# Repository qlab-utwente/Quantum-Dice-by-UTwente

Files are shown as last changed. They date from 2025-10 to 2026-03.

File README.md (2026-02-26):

# QuantumDice by UTwente

> NEW RELEASE 📢: Quantum Dice V2.0.1
[see](https://github.com/qlab-utwente/Quantum-Dice-by-UTwente/releases)

- Every Quantum Die can entangle with another. No need to use pairs of QD's
- Implementation of Teleportation protocol with 3 or more Quantum Die [See User Guide](USER_GUIDE.md)
- Simplified configuration file
- If you are on version V1.x.x.x  [use this guide](MIGRATION_GUIDE_V1.1.X_TO_V2.0.0.md) to migrate to V2.0.x
- Lots software changes to create a more robust, better maintainable software framework.

Quantum Dice trailer (https://www.youtube.com/watch?v=Ihkr6yNOIKE)

flyer

In this repo you can find all relevant files, including assembly instructions, 3D printing files, and the parts list. Based on this information, you can build the Quantum Dice yourself.

For further information see [Quantum Dice by University of Twente](https://www.utwente.nl/en/mesaplus/education/quantum-dice/)

You can find more information about the dice in our article, including didactical approaches, for which a preprint is available on [*arXiv*](https://arxiv.org/abs/2510.04931)

Content of this repo:

- [Arduino Code](/QuantumDice/)
- [Firmware upload procedure](/SETUP.md)
- [3D printfiles](/3D%20print%20files/)
- [Construction manual](/3D%20print%20files/ConstructionManual.md)
- [Bill of Material and parts sourcing calculator](/3D%20print%20files/Bill%20of%20Material%20quantum%20dice.xlsx)
- [Arduino Technical documentation](/QuantumDice/technical%20documentation.md) and [Installation and configuration Arduino IDE](Arduino/QuantumDice/README.md)

## Contribution

Your contribution is welcome and appreciated to improve the quality and functionality of the Quantum Dice.

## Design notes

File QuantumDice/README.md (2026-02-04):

# Programming the QuantumDice by UTwente

---

## Table of Contents

1. [Introduction](#1-introduction)
2. [Technical Overview](#2-technical-overview)
3. [Arduino IDE Setup](#3-arduino-ide-setup)
   - 3.1 [Install Arduino IDE](#31-install-arduino-ide)
   - 3.2 [Install ESP32 Board Support](#32-install-esp32-board-support)
   - 3.3 [Configure Board Settings](#33-configure-board-settings)
   - 3.4 [Install Required Libraries](#34-install-required-libraries)
4. [First Time Setup](#4-first-time-setup)
   - 4.1 [Initial Upload - Blink Test](#41-initial-upload---blink-test)
   - 4.2 [Board Configuration](#42-board-configuration)
5. [Programming the QuantumDice](#5-programming-the-quantumdice)
   - 5.1 [Prepare for Upload](#51-prepare-for-upload)
   - 5.2 [Upload the Sketch](#52-upload-the-sketch)
   - 5.3 [Verify Operation](#53-verify-operation)

---

## 1. Introduction

This guide provides step-by-step instructions for programming and configuring the QuantumDice hardware. Before beginning, ensure you have a USB-C cable and have installed the Arduino IDE on your computer.

> **⚠️ CRITICAL SAFETY WARNING:** Always disconnect the 4-wire power cable before connecting the USB cable to prevent permanent damage to the board! For easier access to the boot and reset buttons and to avoid stress on the display cables, disconnect both the upper and lower screens from the ProcessorBoard during programming.

---

## 2. Technical Overview

The QuantumDice is built on an **ESP32-S3 N16R8 module** and includes several key components:

**Partitions:**
A custom partition setting is used to include a **littlFS** partition. Therefor the file `partitions.csv` must be added to the sketch folder. See [partitions.csv](partitions.csv)

**Display System:**

- Six round TFT displays with SPI interface
- Each display controlled via individual CS-pin connected to a digital port

**Sensors and Components:**

- **BNO055 IMU sensor**: Measures rotation and position of the dice. I2C protocol.
- ESP32 random generator
- Push button for user input
- Battery voltage monitoring system

**Communication:**

- ESP-NOW protocol enables peer-to-peer communication between paired dice
- Automatic neighbor discovery via mesh networking

**Data Storage:**

- Configuration data stored in LittleFS
- Configuration file (called XXXXX_config.txt where XXXXX is the Set Name of the dice)
- The system automatically detects and loads the config file on boot
- [See example configs](/example_configs/)

**Reference Documentation:**

- [ESP32-S3 N16R8 Datasheet](https://www.espressif.com/sites/default/files/documentation/esp32-s3-wroom-1_wroom-1u_datasheet_en.pdf)
- [BNO055 IMU Datasheet](https://nl.mouser.com/datasheet/3/1046/1/bst-bno055-ds000.pdf)

---

## 3. Arduino IDE Setup

### 3.1 Install Arduino IDE

Download and install the latest version of [Arduino IDE 2.x](https://docs.arduino.cc/software/ide/#ide-v2) for your operating system.

### 3.2 Install ESP32 Board Support

1. Open Arduino IDE
2. Navigate to **File > Preferences**
3. In the "Additional Boards Manager URLs" field, add:

   ```
   https://raw.githubusercontent.com/espressif/arduino-esp32/gh-pages/package_esp32_index.json
   ```

4. Click **OK** to save
5. Go to **Tools > Board > Boards Manager**
6. Search for "ESP32"
7. Install **"esp32 by Espressif Systems"**
8. Wait for installation to complete

> **⚠️ IMPORTANT:** Use ESP32 version 3.3.2 from the Board Manager for compatibility.

### 3.3 Configure Board Settings

Select the following settings from the **Tools** menu:

| Setting | Value |
|---|---|
| **Board** | ESP32S3 Dev Module |
| **USB CDC On Boot** | Enabled *(critical for native USB)* |
| **USB Mode** | USB-OTG (TinyUSB) or Hardware CDC and JTAG |
| **Flash Size** | 16MB (128Mb) |
| **PSRAM** | OPI PSRAM |
| **Partition Scheme** | custom |

### 3.4 Install Required Libraries

Install the following libraries via **Tools > Manage Libraries**:

- BNO055 by Adafruit
- Adafruit Unified Sensor
- Adafruit GFX
- Adafruit GC9A01A
- Button2

Your Arduino IDE is now ready for QuantumDice development.

---

## 4. First Time Setup

When connecting a fresh ESP32-S3 module (ESP32-S3N16R8) to Arduino IDE for the first time, you may see continuous reboot messages in the Serial monitor:

```
invalid header: 0xffffffff
invalid header: 0xffffffff
ESP-ROM:esp32s3-20210327
Build:Mar 27 2021
rst:0x7 (TG0WDT_SYS_RST),boot:0x2b (SPI_FAST_FLASH_BOOT)
Saved PC:0x40048839
invalid header: 0xffffffff
...
```

This is **completely normal** for a fresh module from the supplier. Here's what's happening:

- **`invalid header: 0xffffffff`** - The bootloader is searching for valid firmware in flash memory but finding only erased flash (0xFFFFFFFF = all bits set high = empty state)
- **`rst:0x7 (TG0WDT_SYS_RST)`** - Watchdog timer reset triggered because no valid firmware was found to execute
- **Bootloop** - The module continuously resets because there's no program to run

The ESP32-S3 module has never been programmed and needs its first firmware upload.

### 4.1 Initial Upload

When programming an ESP32-S3 for the first time, a specific initialization procedure is required.

> **⚠️ REMINDER:** Disconnect the 4-wire power cable before connecting USB!

#### Step 1: Load the QuantumDice sketch

1. Go to **File > Open** and select the QuantumDice.ino file

#### Step 2: Enter Download Mode

For the first upload, manually put the ESP32-S3 into download mode. See attached image for the locations of the **BOOT** and **RESET** button.


1. **Hold down** the **BOOT** button
2. While holding BOOT, **press and release** the **RESET** button
3. **Release** the **BOOT** button

Your board is now in download mode and ready to receive code.

*Alternative method:* Hold the BOOT button while plugging in the USB cable.

#### Step 3: Select COM Port

1. Go to **Tools > Port**
2. Select the COM port for your ESP32-S3:
   - **Windows:** COM# (e.g., COM3)
   - **Mac:** /dev/cu.usbmodem# or /dev/tty.usbmodem#
   - **Linux:** /dev/ttyACM# or /dev/ttyUSB#

#### Step 4: Upload the Sketch

1. Click the **Upload** button (right arrow icon)
2. Wait for compilation and upload to complete
3. You should see "Connecting..." followed by upload progress
4. Once complete, **press the RESET button** on your board

The QuantumDice should now be running.

**After this initial upload, future uploads will not require the BOOT button procedure.**

### 4.2 Board Configuration

The board configuration is performed with a XXXXX_config.txt file. You can use the  enclosed [TEST1_config.txt](/example_configs/TEST1_config.txt) as a starter.

Uploading the config file with
[ESPConnect](https://thelastoutpostworkshop.github.io/ESPConnect/) tool (need Google Chrome to run). For complete instructions, see the [Setup Guide](../README.md).

---

## 5. Programming the QuantumDice

### 5.1 Prepare for Upload

> **⚠️ REMINDER:** Always disconnect the 4-wire power cable before connecting USB!

**Before programming:**

1. Remove the top and bottom (blue) cups from the dice
2. Disconnect the 4-wire power cable
3. Optionally disconnect the display FPC cables for easier access to buttons
4. Connect a USB-C cable to the underside of the ProcessorPCB

### 5.2 Upload the Sketch

1. Open the sketch in Arduino IDE
2. Connect the ProcessorPCB via USB-C cable
3. Select the correct communication port from **Tools > Port**
4. Click **Upload** to compile and upload the sketch
5. Wait for the upload to complete

### 5.3 Verify Operation

After uploading, open the **Serial Monitor** (baud rate: **115200**) to view debugging information.

**Expected Startup Sequence:**

The Serial Monitor will display:

- Loaded configuration (Dice ID, colors, timing constants)
- Hardware pin configuration
- Display initialization
- BNO055 sensor detection and calibration status
- ESP-NOW initialization with MAC address
- State machine initialization
- Welcome sequence with logo displays

**Example Output:**

```text
[LOG]	
[LOG]	╔════════════════════════════════════════╗
[LOG]	║      QUANTUM DICE INITIALIZATION       ║
[LOG]	╚════════════════════════════════════════╝

[LOG]	/home/twan/Development/Quantum-Dice-by-UTwente/QuantumDice/QuantumDice.ino Jan 26 2026 21:09:54
[L] FW: 2.0.0
[LOG]	Step 1: Initializing filesystem and configuration...
[LOG]	
[DEBUG]	Mounting LittleFS...
[DEBUG]	LittleFS mounted successfully
[D] Total: 4194304 bytes, Used: 8192 bytes
[D] Found config file: DEFAULT_config.txt
[D] Loading global config from /DEFAULT_config.txt...
[DEBUG]	LittleFS mounted successfully
[DEBUG]	Loading config from /DEFAULT_config.txt
[D] Loaded 4 entanglement colors
[DEBUG]	Config loaded successfully
[D] Loaded global config from: /DEFAULT_config.txt
[LOG]	✓ Filesystem and configuration ready!

[LOG]	=== Global Configuration ===
[L] Dice ID: DEFAULT
[L] X Background: 0x0000 (0)
[L] Y Background: 0x0000 (0)
[L] Z Background: 0x0000 (0)
[L] Entangle Colors (4): ffe0, 7e0, 7ff, f81f
[LOG]	
[L] Color Flash Timeout: 250 ms
[L] RSSI Limit: -35 dBm
[L] Is SMD: true
[L] Is Nano: false
[L] Deep Sleep Timeout: 300000 ms
[L] Checksum: 0x00
[LOG]	============================
[LOG]	
Step 2: Initializing hardware...
[LOG]	
Initializing hardware pins...
Hardware pins initialized successfully!
[LOG]	
=== Hardware Pin Configuration ===
[L] Board Type: DEVKIT
[L] Screen Type: SMD
[LOG]	
TFT Display Pins:
[L]   CS:  GPIO10
[L]   RST: GPIO48
[L]   DC:  GPIO47
[LOG]	
Screen CS Pins:
[L]   Screen 0: GPIO4
[L]   Screen 1: GPIO5
[L]   Screen 2: GPIO6
[L]   Screen 3: GPIO7
[L]   Screen 4: GPIO15
[L]   Screen 5: GPIO16
[L] 
ADC Pin: GPIO2
[LOG]	==================================

[L]  - Dice ID: [LOG]	DEFAULT
[L] Board type: [LOG]	DEVKIT
[L] Connectie type isSMD: [LOG]	SMD
Initializing displays...
Displays initialized successfully!
[D] Qlab logo on screen: [DEBUG]	14
[LOG]	
Step 3: Initializing IMU sensor...
[LOG]	
[L] Initializing BNO055... E (3501) i2c.master: I2C transaction unexpected nack detected
E (3502) i2c.master: s_i2c_synchronous_transaction(945): I2C transaction failed
E (3503) i2c.master: i2c_master_transmit_receive(1248): I2C transaction failed
E (3520) i2c.master: I2C transaction unexpected nack detected
...
E (3773) i2c.master: s_i2c_synchronous_transaction(945): I2C transaction failed
E (3775) i2c.master: i2c_master_transmit_receive(1248): I2C transaction failed
[LOG]	detected.
[L] Applying axis remapping... [LOG]	done.
[L] Waiting for stable readings... [L] OK ([L] 9.46[L]  m/s² after [L] 1[LOG]	 attempts)
[L] Stabilizing baseline... [LOG]	done.
[LOG]	✓ BNO055 initialization complete!
[D] QR code on screen: [DEBUG]	1
[D] Einstein on screen: [DEBUG]	8
[D] UTwente logo on screen: [DEBUG]	7
[LOG]	
Step 4: Completing initialization...
[LOG]	
ESP-NOW initialized successfully!
[D] MAC Address is : D0[D] :CF[D] :13[D] :36[D] :15[D] :90[D] 
[LOG]	ESP-NOW initialized successfully!
[D] MAC Address is : D0[D] :CF[D] :13[D] :36[D] :15[D] :90[D] 
[LOG]	StateMachine Begin: Calling onEntry for initial state
[D] StateMachine: CLASSIC | IDLE | PURE
[DEBUG]	=== Entering CLASSIC MODE ===
[DEBUG]	Entering N2 case
[DEBUG]	Entering N3 case
[DEBUG]	Entering N6 case
[DEBUG]	Entering N5 case
[DEBUG]	Entering N4 case
[DEBUG]	Entering N1 case
[LOG]	
[LOG]	╔════════════════════════════════════════╗
[LOG]	║       SETUP COMPLETE - READY!          ║
[LOG]	╚════════════════════════════════════════╝
```

> **Note:** You may see some I2C error messages during initialization. These are typically harmless if the sensors are detected successfully afterward.

**Your QuantumDice is now programmed and ready to use!**

---

## Troubleshooting

**Upload fails:**

- Ensure BOOT button procedure was followed for first-time uploads
- Check USB cable connection and try a different cable
- Verify correct COM port is selected
- Confirm 4-wire power cable is disconnected

**Sensor errors:**

- Check I2C connections
- Verify sensors are properly seated

**Display issues:**

- Ensure FPC cables are properly connected
- Check CS pin assignments in code match your hardware version

---

*For additional support, refer to the QuantumDice GitHub repository or contact the UTwente development team.*

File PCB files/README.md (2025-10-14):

# Power Board and Processor Board Information

In this directory you find the files needed to order your Printed Circuit Boards (PCB) for the ProcessorPCB (left) and the PowerPCB (right).

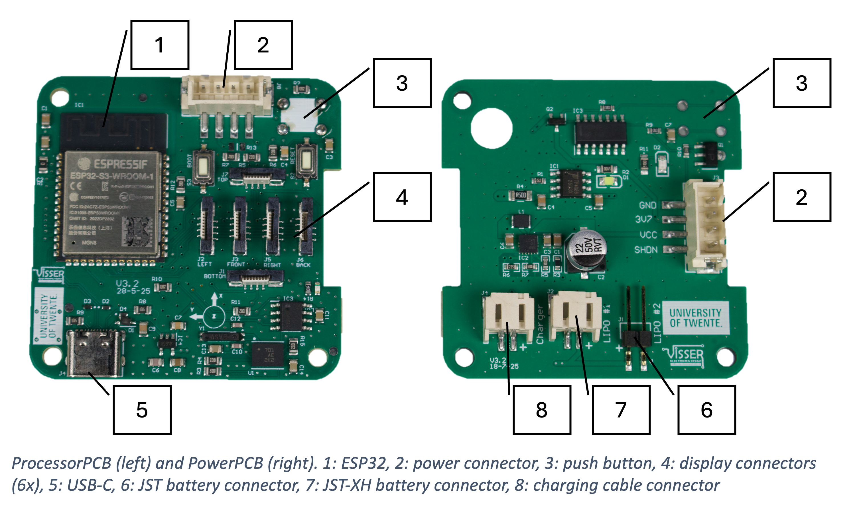
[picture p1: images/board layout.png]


Per board the following files are available:
- Gerber files in ZIP format
- Bill of Material (BOM) list
- Pick and place file

---

## PCB Fabrication

The Gerber files can be used to fabricate the PCBs. This can be done by [JLCPCB.com](https://www.jlcpcb.com) or [PCBway.com](https://www.pcbway.com) or equivalent.

Important to notice is that the ProcessorPCB is a 4-layer board and the PowerPCB is a 2-layer board.

---

## Assembly of Boards

In the BOM file the required components are listed. The numbers refer to JLCPCB Part Numbers. This number can be used to order parts from JLCPCB.

JLCPCB offers a service to assemble the PCB after PCB fabrication called **PCB Assembly**.

After uploading the Gerber files in JLCPCB (default settings are OK), select PCB Assembly.

### ProcessorPCB

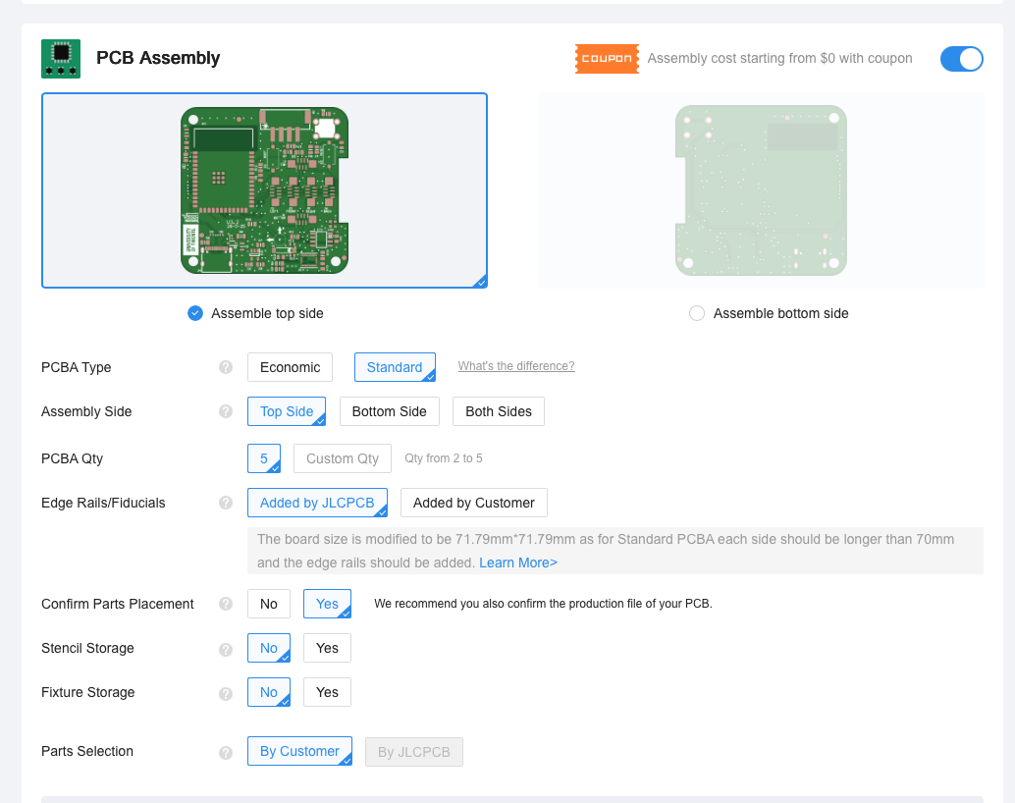
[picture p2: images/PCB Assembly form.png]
PCB Assembly Form


- Select *Assemble top side*
- Select *Standard*
- Select *Confirm Parts Placement* (From my own experience JLCPCB can make mistakes with the orientation of components. With this option you will be asked to verify component orientation)

Next upload BOM and Pick and Place file.

The orientation is indicated in Magenta (right PCB):

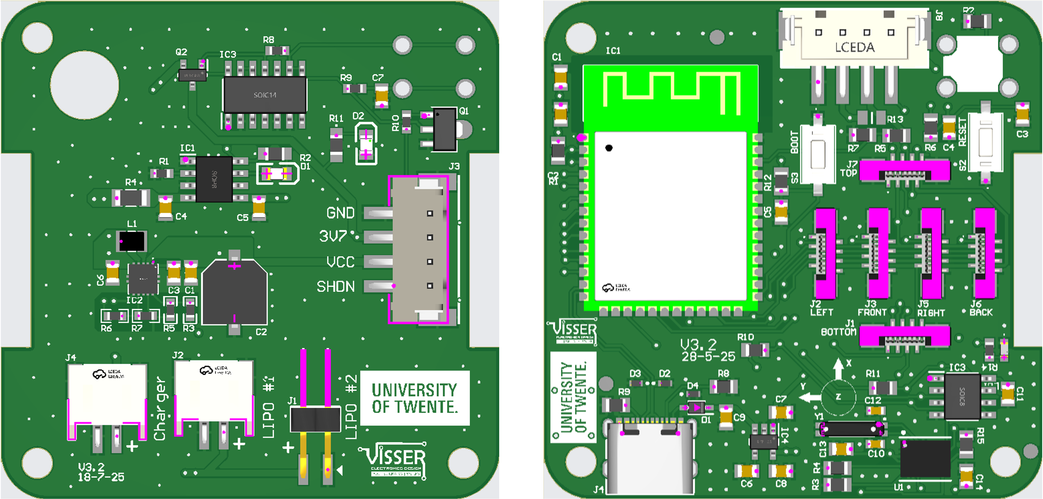
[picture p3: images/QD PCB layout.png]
QD PCB Layout


### PowerPCB

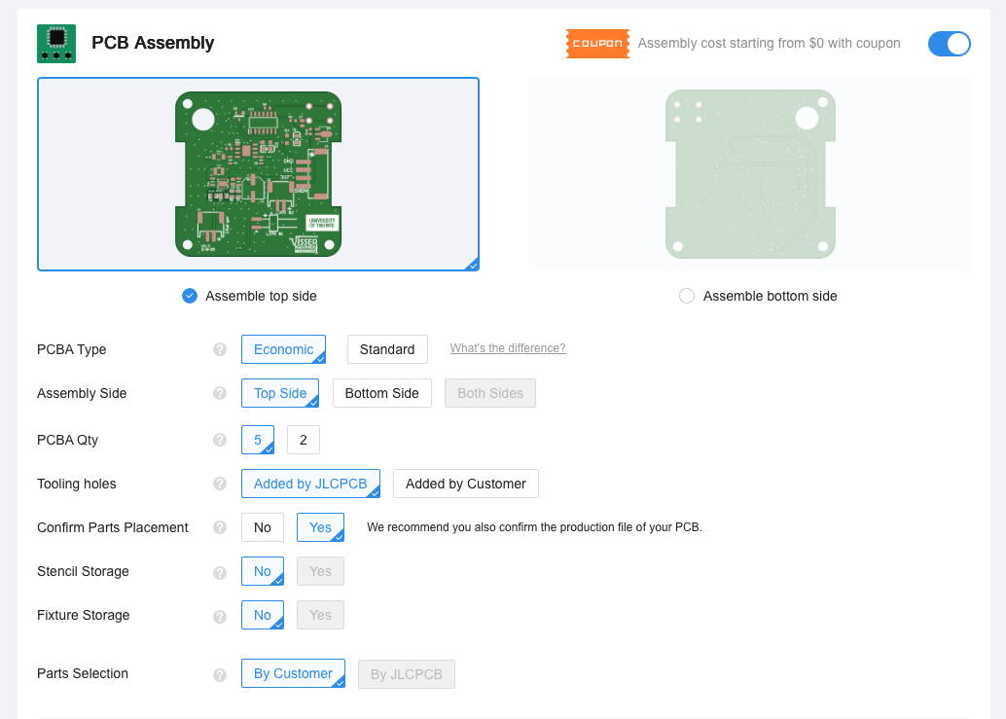
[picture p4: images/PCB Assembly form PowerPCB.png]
PCB Assembly Form PowerPCB


- Select *Assemble top side*
- Select *Economic*
- Select *Confirm Parts Placement* (From my own experience JLCPCB can make mistakes with the orientation of components. With this option you will be asked to verify component orientation)

Next upload BOM and Pick and Place file.

The orientation of D1 and D2 can go wrong (opposite mount). See detail:

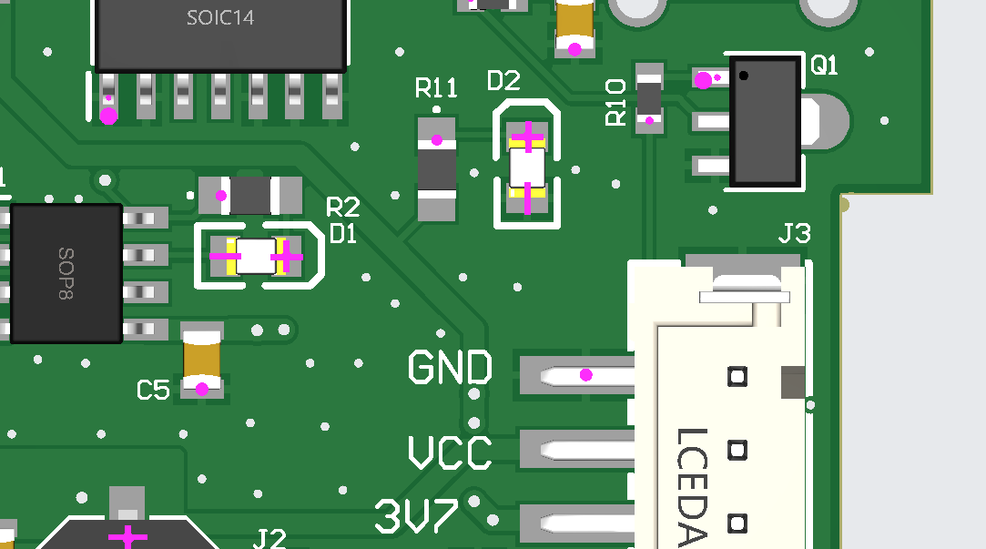
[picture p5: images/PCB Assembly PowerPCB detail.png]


### Soldering push button

On both PCB's a **Tactile Pushbutton 4pin 6*6*6 mm** (See BOM list) must be soldered on the *Bottom Side* of the PCB. The height of the button must be 6 mm!

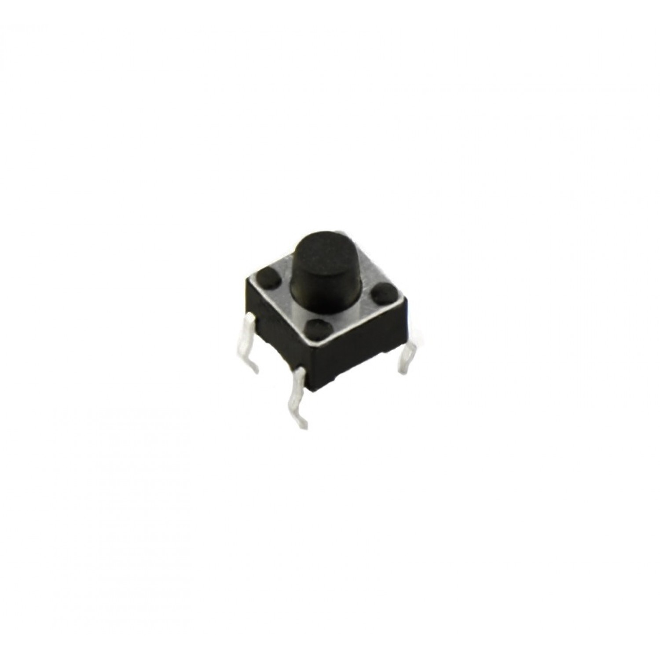
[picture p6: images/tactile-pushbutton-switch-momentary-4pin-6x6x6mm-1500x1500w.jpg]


## Final Notes

After assembly, carefully inspect both boards for:
- Correct component orientation
- Proper soldering quality
- No bridged connections

Once you receive your assembled PCBs, verify all components against the BOM before powering up the boards for the first time.

For questions or issues during the ordering process, refer to the manufacturer's documentation or contact their support team.

---

**Good luck with your PCB fabrication and assembly!**

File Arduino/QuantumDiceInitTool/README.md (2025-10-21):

# Quantum Dice Init Tool - User Manual

## Overview

This tool provides a comprehensive setup interface for initializing ESP32-S3 based Quantum Dice devices. It handles MAC address retrieval, cryptographic chip configuration, IMU sensor calibration, and device configuration storage.

Once uploaded open Serial monitor 

---

## Menu Items Reference

### Main Menu Options

| Option | Function | Purpose | Permanent? |
|---|---|---|---|
| **1** | Get MAC Address | Retrieves and formats the device's unique MAC address for configuration | No |
| **2** | Configure ATECC508a | Initializes and locks the cryptographic co-processor with SparkFun settings | **YES - PERMANENT** |
| **3** | Calibrate BNO055 Sensor | Performs IMU sensor calibration and stores offsets in EEPROM | No (can recalibrate) |
| **4** | Test BNO055 Sensor | Displays live sensor data to verify calibration quality | No |
| **5** | Clear EEPROM | Erases all EEPROM data (calibration + configuration) | No (requires confirmation) |
| **6** | Configure EEPROM Settings | Interactive device configuration setup and storage | No (can reconfigure) |
| **M** | Show Menu | Redisplays the main menu | No |

---

## First-Time Setup Workflow

Follow this step-by-step guide to initialize a new device from scratch (empty EEPROM).

---

### Step 1: Get MAC Address

**Purpose:** Retrieve the unique MAC address needed for device identification and configuration.

1. Press **`1`** in the main menu
2. Wait for WiFi initialization (1-2 seconds)
3. You'll see output similar to:
```
   --- Getting MAC Address ---
   Original MAC Address: D0:CF:13:36:40:88
```

4. **Copy** the formatted MAC address line
5. **Save it** for use in Step 4 (Configuration)
6. Press **`M`** to return to menu

**Notes:**
- Each device has a unique MAC address
- You'll need this for Device A, B1, and B2 configurations

---

### Step 2: Configure ATECC508a Cryptographic Chip

**⚠️ WARNING: THIS STEP IS PERMANENT AND CANNOT BE UNDONE!**

**Purpose:** Initialize the hardware security chip for cryptographic operations and secure key storage. This device must be locked first before it can be used.

1. Press **`2`** in the main menu
2. The tool will detect the ATECC508a and display:
```
   ✓ ATECC508a detected - I2C connection good
   Serial Number: 0123456789ABCDEF
   Config Zone: NOT Locked
   Data/OTP Zone: NOT Locked
   Data Slot 0: NOT Locked
```

3. Type **`Y`** to confirm (or any other key to cancel)
4. The configuration process will run:
```
   Write Config:   ✓ Success
   Lock Config:    ✓ Success
   Key Creation:   ✓ Success
   Lock Data-OTP:  ✓ Success
   Lock Slot 0:    ✓ Success
```

5. Verify all steps show **`✓ Success`**
6. Press **`M`** to return to menu

**Notes:**
- The public key will be generated and displayed after locking
- If already configured, the tool will inform you and skip this step

---

### Step 3: Calibrate BNO055 IMU Sensor

**Purpose:** Calibrate the 9-axis IMU sensor for accurate motion detection and orientation tracking.

1. Press **`3`** in the main menu
2. The tool will detect the BNO055 and display sensor details
3. For new devices, it will show:
```
   ⚠ No calibration data found in EEPROM
   Starting calibration process...
```

4. **Calibration Process:**

   See [Bosch calibration instruction on Youtube](https://www.youtube.com/watch?v=Bw0WuAyGsnY)
   and [Adafruit calibration article](https://learn.adafruit.com/adafruit-bno055-absolute-orientation-sensor/device-calibration)
   
   The tool will display real-time calibration status:
```
   Cal: Sys:0 G:0 A:0 M:0 | Linear: 0.450 m/s² [⚠⚠ HIGH OFFSET - Keep calibrating!]
```

   **Calibration values range from 0 (uncalibrated) to 3 (fully calibrated):**
   - **Sys** = System (overall status)
   - **G** = Gyroscope
   - **A** = Accelerometer  
   - **M** = Magnetometer

5. **Perform these movements until all values reach 3:**

   **For Magnetometer (M):**
   - Move the device in a **figure-8 pattern**
   - Cover all orientations in 3D space
   - Continue until M reaches 3

   **For Gyroscope (G):**
   - **Slowly rotate** the device around all three axes
   - X-axis: rotate left/right
   - Y-axis: rotate forward/backward
   - Z-axis: rotate clockwise/counterclockwise
   
   **For Accelerometer (A):**
   - Place device in **6 different orientations**:
     - Face up, face down
     - Left side, right side
     - Top edge, bottom edge
   - Hold each position for 2-3 seconds

6. **Monitor Linear Acceleration Offset:**
```
   Linear: 0.120 m/s² [✓✓ Excellent offset!]
```
   
   **Target: < 0.15 m/s²**
   - **< 0.15**: Excellent ✓✓
   - **0.15-0.30**: Good ✓
   - **0.30-0.50**: Moderate ⚠
   - **> 0.50**: High - keep calibrating ⚠⚠

7. When fully calibrated (Sys:3 G:3 A:3 M:3):
```
   ✓ Fully calibrated!
   Final linear acceleration offset: 0.0823 m/s² - Excellent! ✓✓
   
   Saving calibration to EEPROM...
   ✓ Calibration saved!
```

8. Press **`M`** to return to menu

**Notes:**
- Calibration typically takes 2-5 minutes
- Move **slowly and smoothly** for best results
- Press **`Q`** anytime to quit without saving
- For acceleration testing 
- You can recalibrate anytime from the menu
- Use Option 4 to test sensor accuracy after calibration

---

### Step 4: Configure Device Settings in EEPROM

**Purpose:** Set up device-specific parameters including MAC addresses, display colors, and operational settings.

1. Press **`6`** in the main menu
2. For empty EEPROM, you'll see:
```
   ⚠ No valid configuration found in EEPROM
   Let's configure your device!
   
   Creating new configuration...
```

3. **Interactive Field-by-Field Configuration:**

   The tool will prompt for each setting with a default value shown in brackets:
```
   ----------------------------------------
   Dice ID [TEST1]: 
```

   - maximum of 5 characters
   - **Press ENTER** to accept the default value
   - **Type a new value** and press ENTER to change it
   - Important fields: Dice ID, Device A MAC, Device B MAC. The remaining fields the defaults are ok
   - When using the Quantum Dice for **Teleportation** demonstration, the MAC Address of the 3rd dice is needed at Device B2 MAC. 

4. **Configuration Fields:**

   | Field | Description | Example | Notes |
   |-------|-------------|---------|-------|
   | **Dice ID** | Unique identifier (max 5 chars) | `DICE_A` | Alpha-numeric |
   | **Device A MAC** | Primary device MAC address | `D0:CF:13:36:40:88` | From Step 1 |
   | **Device B1 MAC** | Secondary device 1 MAC | `D0:CF:13:33:58:5C` | From Step 1 |
   | **Device B2 MAC** | Secondary device 2 MAC | `DC:DA:0C:21:02:44` | From Step 1 |
   | **X Background Color** | Display color (hex) | `0x0000` | 16-bit RGB565 |
   | **Y Background Color** | Display color (hex) | `0x0000` | 16-bit RGB565 |
   | **Z Background Color** | Display color (hex) | `0x0000` | 16-bit RGB565 |
   | **Entanglement AB1 Color** | Connection color (hex) | `0xFFE0` | Yellow |
   | **Entanglement AB2 Color** | Connection color (hex) | `0x07E0` | Green |
   | **RSSI Limit** | Signal strength threshold for entanglement (dBm) | `-35` | -100 to 0. |
   | **Is NANO board?** | Board type | `N` | Y=NANO, N=DEVKIT |
   | **Is SMD screen?** | Screen type | `Y` | Y=SMD, N=HDR |
   | **Always Seven mode?** | Debug mode | `N` | Y/N |
   | **Random Switch Point** | Randomness threshold (0-100) | `50` | 0-100 |
   | **Tumble Constant** | Minimum amount of rolling | `0.2` | 0.0-10.0 |
   | **Deep Sleep Timeout** | Auto-sleep time (seconds) | `300` | 10-3600 |

5. **MAC Address Entry:**
   
   Enter MAC addresses in the format: `AA:BB:CC:DD:EE:FF`
   
   Example:
```
   Device A MAC [D0:CF:13:36:40:88]
   Enter MAC (format: AA:BB:CC:DD:EE:FF) or press ENTER:
   D0:CF:13:36:40:88
   ✓ MAC set to: D0:CF:13:36:40:88
```

6. **Configuration Summary:**

   After entering all fields, review the complete configuration:
```
   ========================================
     Configuration Summary
   ========================================
   
   Dice ID: DICE_A
   Device A MAC:  D0:CF:13:36:40:88
   Device B1 MAC: D0:CF:13:33:58:5C
   ...
   
   Write this configuration to EEPROM?
   Type 'Y' to confirm or any other key to cancel:
```

7. Type **`Y`** to save to EEPROM
8. Verification will run automatically:
```
   ✓ Configuration written to EEPROM successfully!
   Verifying...
   ✓ Verification successful!
```

9. Press **`M`** to return to menu

**Notes:**
- Configuration can be changed anytime (not permanent)
- Existing values will be shown as defaults on subsequent edits
- All fields are validated before writing to EEPROM
- Invalid entries will show a warning and use the previous value

---

## Verification and Testing

After completing all setup steps, verify everything is working:

### Verify BNO055 Calibration

1. Press **`4`** (Test BNO055 Sensor)
2. Place device on a stable, flat surface
3. Observe the linear acceleration reading:
```
   Cal: Sys:3 G:3 A:3 M:3 | Linear: 0.098 m/s² [✓✓ Excellent] | X:0.012 Y:0.034 Z:0.023
```
4. **When stationary, linear acceleration should be < 0.40 m/s²**
5. Press any key to exit

### Verify Configuration

1. Press **`6`** (Configure EEPROM Settings)
2. Review the displayed configuration
3. Press **`N`** to keep current settings
4. All values should match your intended configuration

---

## Troubleshooting

### Calibration Won't Complete
- Move device more slowly
- Ensure no magnetic interference nearby
- Try recalibrating in a different location
- System value may reach 3 before all individual sensors do

### Configuration Validation Failed
- Check MAC address format (must be 12 hex digits)
- Verify RSSI limit is between -100 and 0
- Ensure Dice ID is not empty and < 16 characters
- Check numeric ranges for all parameters

### Double-Enter Issues
- Use Arduino Serial Monitor with "Newline" line ending
- Wait for prompt before entering next value
- If a field is skipped, restart configuration

---

## Safety Notes

⚠️ **CRITICAL WARNINGS:**

1. **ATECC508a Configuration:**
   - Configuration locks are **PERMANENT**
   - **Cannot be reversed or changed**
   - Once locked, the chip configuration is fixed for life
   - Only proceed when you are certain

2. **EEPROM Operations:**
   - Clear EEPROM erases **ALL** data (calibration + config)
   - Always backup important configurations
   - Clearing requires recalibration and reconfiguration

3. **Power During Operations:**
   - Keep device powered during EEPROM writes
   - Do not disconnect during ATECC508a locking
   - Stable USB power required throughout setup

---

## Quick Reference Card

**First-Time Setup Order:**
```
1 → Get MAC Address          [Copy and save]
2 → Configure ATECC508a      [⚠️ PERMANENT - Type Y]
3 → Calibrate BNO055         [Move device until Sys:3]
6 → Configure EEPROM         [Enter all fields, Type Y]
4 → Test BNO055              [Verify < 0.15 m/s²]
```

**Testing/Maintenance:**
```
4 → Test sensor readings
6 → View/edit configuration
3 → Recalibrate if needed
```

**Emergency:**
```
5 → Clear EEPROM [Erases everything - requires full reconfiguration]
```

---

*Document Version: 1.0*  
*Compatible with: ESP32-S3 Unified Sensor Setup Tool*

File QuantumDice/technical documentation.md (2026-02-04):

# Quantum Dice - Technical Documentation

**Version:** 2.0.0  
**Platform:** ESP32-S3 N16R8  
**Framework:** Arduino

---

## Table of Contents

1. [System Overview](#1-system-overview)
2. [Hardware Architecture](#2-hardware-architecture)
3. [Software Architecture](#3-software-architecture)
4. [State Machine](#4-state-machine)
5. [Quantum Mechanics Implementation](#5-quantum-mechanics-implementation)
6. [Communication Protocol](#6-communication-protocol)
7. [Configuration System](#7-configuration-system)
8. [Motion Detection](#8-motion-detection)
9. [Display System](#9-display-system)
10. [Data Structures](#10-data-structures)
11. [Code Modules](#11-code-modules)

---

## 1. System Overview

The Quantum Dice is an interactive educational device that demonstrates quantum mechanical principles through a physical dice system. It operates in two modes:

- **Classic Mode**: Functions as a traditional random dice
- **Quantum Mode**: Demonstrates quantum entanglement, superposition, measurement, and teleportation

### Key Features

- Quantum entanglement between multiple dice
- Quantum teleportation between three dice (Alice, Bob, and Measurement)
- Measurement basis correlation
- State persistence (memoization)
- Visual feedback through six circular TFT displays
- Battery-powered with deep sleep capability
- ESP-NOW wireless communication

---

## 2. Hardware Architecture

### Core Components

| Component | Model/Type | Interface | Purpose |
|---|---|---|---|
| **Microcontroller** | ESP32-S3 N16R8 | - | Main processor with 16MB Flash, 8MB PSRAM |
| **IMU Sensor** | Adafruit BNO055 | I2C | 9-DOF orientation, motion detection |
| **Displays (6x)** | GC9A01A Round TFT | SPI | Visual state representation |
| **Button** | Button2 | GPIO_NUM_14 | Mode switching, UI control |
| **Power** | Li-Po Battery | ADC monitoring | Battery voltage monitoring |
| **Communication** | ESP-NOW | WiFi (channel 6) | Peer-to-peer messaging |

### Pin Assignments

The system uses dynamic pin mapping loaded from configuration:

- **Power Control**: GPIO_NUM_18 (REGULATOR_PIN) - keeps power on when HIGH
- **Button Input**: GPIO_NUM_14 (BUTTON_PIN) - user interaction
- **SPI Bus**: Shared among all six displays
- **Display CS Pins**: Configurable per board variant (NANO/DEVKIT, SMD/HDR)
- **I2C Bus**: BNO055 IMU communication

### Display Configuration

Six displays arranged to represent the six faces of a dice:
- **X-axis**: X0, X1 (opposing sides)
- **Y-axis**: Y0, Y1 (opposing sides)
- **Z-axis**: Z0, Z1 (opposing sides)

---

## 3. Software Architecture

### Initialization Sequence

The `setup()` function follows a strict four-step initialization:

```
1. Power Management
   └─ Enable regulator pin immediately

2. Filesystem & Configuration
   ├─ Initialize LittleFS
   ├─ Auto-detect config file
   ├─ Load configuration
   └─ Validate checksum

3. Hardware Initialization
   ├─ Configure GPIO pins
   ├─ Initialize displays
   ├─ Initialize IMU sensor
   └─ Apply axis remapping (NANO variant)

4. State Machine Setup
   ├─ Initialize ESP-NOW
   ├─ Configure button handler
   └─ Enter initial state (CLASSIC/IDLE/PURE)
```

### Main Loop

The `loop()` function operates at **50ms intervals** (UPDATE_INTERVAL):

```cpp
void loop() {
    button.loop();           // Process button events
    stateMachine.update();   // Execute state machine logic
}
```

---

## 4. State Machine

### State Representation

The system state is defined by three orthogonal dimensions:

```cpp
struct State {
    Mode              mode;              // CLASSIC, QUANTUM, LOW_BATTERY
    ThrowState        throwState;        // IDLE, THROWING, OBSERVED
    EntanglementState entanglementState; // PURE, ENTANGLE_REQUESTED, 
                                         // ENTANGLED, POST_ENTANGLEMENT, 
                                         // TELEPORTED
};
```

### Modes

| Mode | Description |
|---|---|
| `CLASSIC` | Traditional random dice, no quantum behavior |
| `QUANTUM` | Full quantum behavior enabled |
| `LOW_BATTERY` | Power-saving mode, prompts for charging |

### Throw States

| State | Description | Entry Condition |
|---|---|---|
| `IDLE` | Dice at rest, awaiting action | Dice stable on table |
| `THROWING` | Dice in motion | Motion detected (tumbling) |
| `OBSERVED` | Measurement complete | Dice stopped and on table |

### Entanglement States

| State | Description |
|---|---|
| `PURE` | No entanglement, superposition |
| `ENTANGLE_REQUESTED` | Awaiting partner confirmation |
| `ENTANGLED` | Quantum correlation active |
| `POST_ENTANGLEMENT` | Partner measured, awaiting our measurement |
| `TELEPORTED` | Received teleported state |

### State Transitions

The system defines **37 state transitions** triggered by various events:

#### Trigger Types

| Category | Triggers |
|---|---|
| **User** | `BUTTON_PRESSED` |
| **Motion** | `START_ROLLING`, `STOP_ROLLING` |
| **Entanglement** | `CLOSE_BY`, `ENTANGLE_REQUEST`, `ENTANGLE_CONFIRM`, `ENTANGLE_STOP` |
| **Measurement** | `MEASURE`, `MEASURE_FAIL`, `MEASUREMENT_RECEIVED` |
| **Teleportation** | `TELEPORT_INITIATED`, `TELEPORT_CONFIRMED`, `TELEPORT_RECEIVED` |
| **System** | `TIMED`, `LOW_BATTERY` |

#### Key Transitions

**Classic ↔ Quantum Mode Switching:**
```
CLASSIC/IDLE/PURE + BUTTON_PRESSED → QUANTUM/IDLE/PURE
QUANTUM/IDLE/PURE + BUTTON_PRESSED → CLASSIC/IDLE/PURE
```

**Entanglement Establishment:**
```
QUANTUM/IDLE/PURE + CLOSE_BY → QUANTUM/IDLE/ENTANGLE_REQUESTED
QUANTUM/IDLE/ENTANGLE_REQUESTED + ENTANGLE_CONFIRM → QUANTUM/IDLE/ENTANGLED
```

**Measurement Flow:**
```
QUANTUM/IDLE/* + START_ROLLING → QUANTUM/THROWING/*
QUANTUM/THROWING/* + STOP_ROLLING → QUANTUM/OBSERVED/*
QUANTUM/OBSERVED/PURE + START_ROLLING → QUANTUM/THROWING/PURE
```

**Teleportation (3-dice system: Alice-Bob-Measurement):**
```
Alice (ENTANGLED) detects nearby M → sends TELEPORT_REQUEST
M receives request → sends TELEPORT_PAYLOAD to Bob → sends TELEPORT_CONFIRM to Alice
Bob receives payload → inherits M's state (may include entanglement to N)
```

### State Functions

Each valid state combination maps to two functions:

```cpp
struct StateFunction {
    void (StateMachine::*onEntry)();      // Called once on state entry
    void (StateMachine::*whileInState)(); // Called repeatedly while in state
};
```

---

## 5. Quantum Mechanics Implementation

### Superposition

When a quantum dice is unobserved (IDLE or THROWING in PURE state), it displays a superposition pattern on all six faces, representing that the outcome is undefined until measured.

### Measurement & Collapse

When the dice stops and becomes stable on a table:

1. **Axis Detection**: IMU determines which face is up (X0, X1, Y0, Y1, Z0, or Z1)
2. **Basis Selection**: The up-face determines the measurement basis (X, Y, or Z axis)
3. **Wave Function Collapse**: A random number (1-6) is generated
4. **State Display**: The measured face shows the number, others show superposition patterns

### Entanglement

When two dice are brought close together (RSSI > configured limit):

```
Dice A (PURE) detects Dice B → sends ENTANGLE_REQUEST
Dice B (PURE) receives request → sends ENTANGLE_CONFIRM with random color
Both dice → ENTANGLED state with shared color
```

**Entanglement Correlation:**

When entangled dice are measured:
- **Same Basis**: Results are **anti-correlated** (opposite faces: 1↔6, 2↔5, 3↔4)
- **Different Basis**: Results are **uncorrelated** (independent random)

**Implementation:**
```cpp
// First dice to measure
diceNumberSelf = selectOneToSix();
sendMeasurements(partner, ...);

// Partner dice measuring after
if (measureAxisSelf == partnerMeasurementAxis) {
    // Same basis - anti-correlated
    diceNumberSelf = selectOppositeOneToSix(partnerDiceNumber);
} else {
    // Different basis - uncorrelated
    diceNumberSelf = selectOneToSix();
}
```

### Memoization (Measurement Consistency)

To maintain quantum mechanical consistency, the system implements **measurement memoization**:

```cpp
// Store last measurement
lastRollBasis  = measureAxisSelf;   // Which axis was measured
lastRollNumber = diceNumberSelf;    // What value was observed

// On subsequent measurement in same basis
if (measureAxisSelf == lastRollBasis && lastRollNumber != NONE) {
    diceNumberSelf = lastRollNumber;  // Return same value
} else {
    diceNumberSelf = selectOneToSix(); // New random value
}
```

This ensures that repeatedly measuring the same face yields the same result, consistent with quantum mechanics.

### Quantum Teleportation

The system implements simplified quantum teleportation with three dice:

**Roles:**
- **Alice (A)**: Has entangled pair with Bob, initiates teleportation
- **Bob (B)**: Entangled with Alice, receives teleported state
- **Measurement (M)**: The dice to be teleported

**Protocol:**

1. **A and B are entangled** (share color)
2. **A detects M nearby** → sends `TELEPORT_REQUEST(target=B)` to M
3. **M sends its state** → `TELEPORT_PAYLOAD` to B, `TELEPORT_CONFIRM` to A
4. **State Transfer:**
   - If M was PURE: B becomes PURE
   - If M was OBSERVED: B receives teleported measurement (shown only in same basis)
   - If M was ENTANGLED to N: B becomes entangled to N (inherits color)
5. **Cleanup:** M returns to PURE, A-B entanglement ends

**Special Case - Entanglement Swapping:**

If M was entangled to another dice N:
```
Before: A-B entangled, M-N entangled
After:  B-N entangled, A and M are PURE
```

This is implemented via `TELEPORT_PARTNER` message to N.

---

## 6. Communication Protocol

### ESP-NOW Configuration

- **Channel**: 6 (ESPNOW_WIFI_CHANNEL)
- **Transport**: Peer-to-peer, WiFi-based
- **Encryption**: None (broadcast discovery)

### Message Structure

```cpp
struct message {
    message_type type;
    union data {
        watchDogData;        // Periodic presence broadcast
        measurementData;     // Measurement result sharing
        entangleConfirmData; // Entanglement color negotiation
        teleportRequestData; // Teleportation request (contains target MAC)
        teleportPayloadData; // Complete state transfer
        teleportPartnerData; // Entanglement partner update
    } data;
};
```

### Message Types

| Type | Direction | Purpose | Data Payload |
|---|---|---|---|
| `WATCH_DOG` | Broadcast | Presence advertisement | Current state |
| `MEASUREMENT` | Peer → Peer | Share observation result | State, axis, number, upside |
| `ENTANGLE_REQUEST` | Initiator → Target | Request entanglement | None |
| `ENTANGLE_CONFIRM` | Target → Initiator | Accept entanglement | RGB565 color |
| `ENTANGLE_DENIED` | Target → Initiator | Reject entanglement | None |
| `TELEPORT_REQUEST` | Alice → M | Initiate teleportation | Bob's MAC address |
| `TELEPORT_CONFIRM` | M → Alice | Teleportation complete | None |
| `TELEPORT_PAYLOAD` | M → Bob | Transfer complete state | State, measurement, entanglement |
| `TELEPORT_PARTNER` | M → N | Update entanglement partner | New partner MAC |

### RSSI-Based Proximity Detection

```cpp
// Typical configuration
rssiLimit = -35  // dBm threshold for "close by"

// Detection logic
if (last_rssi > rssiLimit && last_rssi < -1) {
    // Dice detected nearby
    sendEntangleRequest(last_source);
}
```

### Watchdog Mechanism

Every **500ms** in QUANTUM mode, each dice broadcasts its state:

```cpp
sendWatchDog();  // Broadcasts current State
```

This enables:
- Proximity detection for entanglement
- State synchronization
- Partner monitoring

---

## 7. Configuration System

### Configuration File Structure

Text-based configuration file (e.g., `TEST1_config.txt`):

```ini
# Dice Identification
diceId=TEST1

# Display Background Colors (RGB565 format)
x_background=0x001F    # Blue
y_background=0xF800    # Red  
z_background=0xFFE0    # Yellow

# Entanglement Colors (up to 8)
entang_colors=0xFFE0,0x07E0,0x07FF,0xF81F

# Timing Configuration
colorFlashTimeout=250    # Color flash duration (ms)
deepSleepTimeout=300000   # Deep sleep after 5 min idle (ms)

# Communication
rssiLimit=-35             # RSSI threshold for proximity (dBm)

# Hardware Configuration
isSMD=true               # SMD vs HDR connection type
isNano=true              # NANO vs DEVKIT board type
```

### DiceConfig Structure

```cpp
struct DiceConfig {
    String   diceId;                                    // Unique identifier
    uint16_t x_background, y_background, z_background;  // RGB565 colors
    std::array<uint16_t, 8> entang_colors;              // Palette
    uint8_t  entang_colors_count;                       // Active colors
    uint16_t colorFlashTimeout;                         // Flash duration
    int8_t   rssiLimit;                                 // Proximity threshold
    bool     isSMD;                                     // Pin mapping variant
    bool     isNano;                                    // Board variant
    uint32_t deepSleepTimeout;                          // Power saving
    uint8_t  checksum;                                  // Validation
};
```

### Auto-Configuration Process

```cpp
bool ensureLittleFSAndConfig() {
    1. Mount LittleFS filesystem
    2. Auto-detect config file (*_config.txt)
    3. Load configuration
    4. Validate checksum
    5. If failed: create default config
}
```

### Hardware Pin Mapping

Pins are configured dynamically based on board type:

```cpp
struct HardwarePins {
    uint8_t tft_cs, tft_rst, tft_dc;    // Common TFT control
    uint8_t screen_cs[6];                // Individual display CS
    uint8_t screenAddress[16];           // Display mapping
    uint8_t adc_pin;                     // Battery monitoring
};
```

Variants:
- **NANO + SMD**: Specific pin layout for Arduino Nano ESP32 with SMD screens
- **NANO + HDR**: Header-based connections
- **DEVKIT + SMD/HDR**: ESP32-S3 DevKit variants

---

## 8. Motion Detection

### BNO055 IMU Sensor

The system uses polymorphic IMU abstraction:

```cpp
class IMUSensor {
    virtual bool moving() = 0;
    virtual bool stable() = 0;
    virtual bool on_table() = 0;
    virtual IMU_Orientation orientation() = 0;
    virtual void resetTumbleDetection() = 0;
    virtual bool tumbled() = 0;
};
```

### Motion Detection Algorithm

**Parameters:**
- `motionThreshold`: 0.5 m/s² (significant acceleration change)
- `stableThreshold`: 0.15 m/s² (minimal movement)
- `stableCountRequired`: 5 consecutive stable samples

**Logic:**
```cpp
accelChange = abs(currentAccelMag - prevAccelMag);

if (accelChange > motionThreshold) {
    isMoving = true;
    stableCounter = 0;
} else if (accelChange < stableThreshold) {
    stableCounter++;
    if (stableCounter >= stableCountRequired) {
        isMoving = false;  // Confirmed stable
    }
}
```

### Orientation Detection

Determines which face is up by analyzing gravity vector:

```cpp
enum IMU_Orientation {
    ORIENTATION_Z_UP,      // Z+ face up
    ORIENTATION_Z_DOWN,    // Z- face up
    ORIENTATION_X_UP,      // X+ face up
    ORIENTATION_X_DOWN,    // X- face up
    ORIENTATION_Y_UP,      // Y+ face up
    ORIENTATION_Y_DOWN,    // Y- face up
    ORIENTATION_TILTED,    // Not aligned
    ORIENTATION_UNKNOWN    // Cannot determine
};
```

**Detection Criteria:**
- Dominant axis must have 9.0–10.5 m/s² (gravity)
- Other axes must be < 2.0 m/s²
- Otherwise classified as TILTED or UNKNOWN

### Tumble Detection

Uses rotation matrix integration to track orientation change:

```cpp
void resetTumbleDetection() {
    // Capture current "up" direction
    xUpStart = accel.x() / accelMagnitude;
    yUpStart = accel.y() / accelMagnitude;
    zUpStart = accel.z() / accelMagnitude;
}

bool tumbled() {
    // Calculate rotation using gyroscope integration
    updateUpVector(deltaTime);
    
    // Dot product between current and initial up vectors
    dotProduct = (xUp * xUpStart) + (yUp * yUpStart) + (zUp * zUpStart);
    
    // Threshold: cos(45°) = 0.707
    return dotProduct < tumbleThreshold;
}
```

**Advantages:**
- Rotation-axis independent (ignores spinning on table)
- Detects only actual rolling/tumbling motion
- Configurable threshold angle

### Axis Remapping

For Arduino Nano ESP32 variant, axes are remapped to match physical orientation:

```cpp
const uint8_t NANO_AXIS_REMAP_CONFIG = 0x06;
imuSensor->setAxisRemap(NANO_AXIS_REMAP_CONFIG, NANO_AXIS_REMAP_CONFIG);
```

---

## 9. Display System

### Hardware Configuration

Six **GC9A01A** round TFT displays (240×240 pixels each):

```cpp
Adafruit_GC9A01A tft0(hwPins.screen_cs[0], hwPins.tft_dc, hwPins.tft_rst);
Adafruit_GC9A01A tft1(hwPins.screen_cs[1], hwPins.tft_dc, hwPins.tft_rst);
// ... tft2 through tft5
```

### Screen Selection System

Screens are addressed via bitmask enum:

```cpp
enum screenselections : uint8_t {
    X0 = 0b000001,      // Individual faces
    X1 = 0b000010,
    Y0 = 0b000100,
    Y1 = 0b001000,
    Z0 = 0b010000,
    Z1 = 0b100000,
    XX = X0 | X1,       // Axis pairs
    YY = Y0 | Y1,
    ZZ = Z0 | Z1,
    ALL = 0b111111,     // All screens
    NO_ONE = 0
};
```

### Display State Mapping

Each face shows a specific `ScreenState`:

```cpp
enum class ScreenStates : uint8_t {
    // Numbers
    N1, N2, N3, N4, N5, N6,
    
    // Quantum states
    MIX1TO6,              // Superposition (white dots)
    MIX1TO6_ENTANGLED,    // Entangled superposition (colored dots)
    
    // Special
    LOWBATTERY, BLANC, QLAB_LOGO, WELCOME, etc.
};
```

### Rendering Pipeline

```cpp
void refreshScreens() {
    // Determine what to show on each face based on:
    // - Current state (mode, throwState, entanglementState)
    // - Dice number (if observed)
    // - Measurement axis
    // - Entanglement color
    
    findValues(stateSelf, diceNumberSelf, upSideSelf,
               x0ScreenState, x1ScreenState,
               y0ScreenState, y1ScreenState,
               z0ScreenState, z1ScreenState);
    
    checkAndCallFunctions(x0, x1, y0, y1, z0, z1);
}
```

### Visual Feedback

| State | Display Pattern | Color |
|---|---|---|
| Superposition (PURE) | Mixed dots all faces | White |
| Entangled (superposition) | Mixed dots all faces | Entanglement color |
| Observed (number) | Dots on measured face | White or color |
| Low Battery | Battery icon | Red |
| Entanglement flash | Brief color pulse | Entanglement color |

### Color System

- **RGB565 Format**: 16-bit color (5-bit red, 6-bit green, 5-bit blue)
- **Background Colors**: Configurable per axis (x_background, y_background, z_background)
- **Entanglement Colors**: Up to 8 colors, randomly selected when establishing entanglement
- **Color Flash**: Brief display on entanglement events (duration: `colorFlashTimeout`)

---

## 10. Data Structures

### Global State Variables

```cpp
// Current dice state
State stateSelf;           // Our current state
State stateSister;         // Partner's last known state

// Measurement values
DiceNumbers    diceNumberSelf;     // Our observed number (1-6 or NONE)
DiceNumbers    diceNumberSister;   // Partner's number
MeasuredAxises measureAxisSelf;    // Which axis we measured (X/Y/Z)
UpSide         upSideSelf;         // Which specific face is up

// Entanglement
uint16_t entanglement_color_self;  // RGB565 color for entanglement
bool     showColors;               // Toggle for color display
bool     flashColor;               // Temporary color flash active
```

### Enumerations

**DiceNumbers:**
```cpp
enum class DiceNumbers : uint8_t {
    NONE, ONE, TWO, THREE, FOUR, FIVE, SIX
};
```

**MeasuredAxises:**
```cpp
enum class MeasuredAxises : uint8_t {
    UNDEFINED,  // Not yet measured
    XAXIS,      // X-axis (X0 or X1 face up)
    YAXIS,      // Y-axis (Y0 or Y1 face up)
    ZAXIS,      // Z-axis (Z0 or Z1 face up)
    ALL,        // Special: all axes
    NA          // Not applicable
};
```

**UpSide:**
```cpp
enum class UpSide : uint8_t {
    NONE,  // Unknown
    X0, X1, Y0, Y1, Z0, Z1,  // Specific faces
    ANY,   // Any face
    NA     // Not applicable
};
```

### StateTransition Structure

```cpp
struct StateTransition {
    // Current state conditions
    std::optional<Mode>              currentMode;
    std::optional<ThrowState>        currentThrowState;
    std::optional<EntanglementState> currentEntanglementState;
    
    // Next state (if transition occurs)
    std::optional<Mode>              nextMode;
    std::optional<ThrowState>        nextThrowState;
    std::optional<EntanglementState> nextEntanglementState;
    
    // Trigger that causes transition
    Trigger trigger;
};
```

---

## 11. Code Modules

### QuantumDice.ino

**Purpose**: Main sketch entry point  
**Key Functions**:
- `setup()`: Four-stage initialization (power, config, hardware, state machine)
- `loop()`: 50ms update cycle for button and state machine

### StateMachine.hpp / .cpp

**Purpose**: Core state machine implementation  
**Key Components**:
- State representation and transitions (37 transitions)
- State handler functions (onEntry, whileInState)
- Message processing logic
- Entanglement and teleportation protocols  
**Lines**: ~1246 lines

### DiceConfigManager.hpp / .cpp

**Purpose**: Configuration file management  
**Key Functions**:
- `load()`: Parse text config file
- `ensureLittleFSAndConfig()`: Auto-detect and load config
- `createDefaultConfigFile()`: Generate default config  
**Features**:
- Checksum validation
- Comment and whitespace handling
- Default value initialization

### IMUhelpers.hpp / .cpp

**Purpose**: Polymorphic IMU sensor abstraction  
**Classes**:
- `IMUSensor`: Abstract base class
- `BNO055IMUSensor`: BNO055 implementation  
**Key Functions**:
- Motion detection (`moving()`, `stable()`)
- Orientation detection (`orientation()`, `on_table()`)
- Tumble tracking (`resetTumbleDetection()`, `tumbled()`)
- Gyroscope integration for rotation matrices  
**Lines**: ~540 lines

### EspNowSensor.hpp

**Purpose**: Template-based ESP-NOW communication wrapper  
**Design Pattern**: Singleton with static interface  
**Key Functions**:
- `Init()`: Initialize ESP-NOW and WiFi
- `Send()`: Transmit message to peer
- `Poll()`: Retrieve received messages from queue
- `AddPeer()`: Register communication partner  
**Features**:
- RSSI extraction from packet headers
- Message queuing
- Callback handling

### Screenfunctions.hpp / .cpp

**Purpose**: Display management and rendering  
**Key Functions**:
- `initDisplays()`: Initialize six GC9A01A displays
- `refreshScreens()`: Update all displays based on state
- `display1to6()`: Show dice numbers
- `displayMix1to6()`: Superposition pattern
- `displayEntangled()`: Entanglement indicator  
**Utilities**:
- `blendColor()`: Alpha blending for smooth visuals
- `drawDot()`: Draw dice dots
- `selectScreens()`: Bitmask-based screen selection

### ScreenStateDefs.hpp / .cpp

**Purpose**: Screen state determination logic  
**Key Functions**:
- `findValues()`: Map quantum state → screen states for each face
- `selectOneToSix()`: Random number generation
- `selectOppositeOneToSix()`: Anti-correlation for entangled dice

### handyHelpers.hpp / .cpp

**Purpose**: Utility functions  
**Key Functions**:
- `initHardwarePins()`: Configure GPIO based on board type
- `initButton()`: Setup button callbacks
- `checkMinimumVoltage()`: Battery level monitoring
- `checkTimeForDeepSleep()`: Power management
- `generateDiceRoll()`: Hardware random number generation

### Queue.hpp

**Purpose**: Generic FIFO queue implementation  
**Template Class**: `Queue<T>`  
**Features**:
- Dynamic resizing
- Circular buffer
- Type-safe

### defines.hpp

**Purpose**: System-wide constants and debug macros  
**Contents**:
- Version string
- Debug/logging macros (debug, info, warn, error)
- Battery voltage thresholds
- Pin definitions

---

## Appendix: Key Algorithms

### Random Number Generation

```cpp
uint8_t generateDiceRoll() {
    // Use ESP32 hardware RNG
    uint32_t random_value = esp_random();
    return (random_value % 6) + 1;  // Returns 1-6
}
```

### Anti-Correlation Mapping

```cpp
DiceNumbers selectOppositeOneToSix(DiceNumbers input) {
    // Opposite faces on a dice sum to 7
    switch (input) {
        case ONE:   return SIX;
        case TWO:   return FIVE;
        case THREE: return FOUR;
        case FOUR:  return THREE;
        case FIVE:  return TWO;
        case SIX:   return ONE;
    }
}
```

### Battery Voltage Monitoring

```cpp
bool checkMinimumVoltage() {
    float voltage = analogRead(hwPins.adc_pin) * (3.3 / 4095.0) * 2.0;
    
    if (voltage < MINBATERYVOLTAGE) {  // 3.40V
        return true;  // Low battery
    }
    return false;
}
```

---

## Performance Characteristics

| Metric | Value | Notes |
|---|---|---|
| Main loop frequency | 20 Hz | 50ms update interval |
| Watchdog broadcast | 2 Hz | Every 500ms (quantum mode only) |
| State machine transitions | <1ms | Typical transition time |
| Display refresh | ~100ms | Full six-screen update |
| Motion detection latency | 50-250ms | Depends on stable count |
| Entanglement discovery | <1s | Proximity-based |
| Configuration load time | <100ms | LittleFS read |

---

## Dependencies

### Arduino Libraries

- **Adafruit_BNO055**: IMU sensor driver
- **Adafruit_Sensor**: Unified sensor abstraction
- **Adafruit_GFX**: Graphics primitives
- **Adafruit_GC9A01A**: Round TFT display driver
- **Button2**: Debounced button handling
- **WiFi**: ESP32 WiFi stack (for ESP-NOW)
- **esp_now**: Peer-to-peer communication
- **LittleFS**: Filesystem for configuration storage

### ESP32 Framework

- **ESP-IDF 5.x** (via Arduino-ESP32 3.3.2)
- **FreeRTOS**: Underlying task scheduler
- **ESP-NOW protocol**: WiFi direct communication

---

## Build Configuration

### Platform Settings

```
Board: ESP32S3 Dev Module
USB CDC On Boot: Enabled
Flash Size: 16MB (128Mb)
PSRAM: OPI PSRAM
Partition Scheme: Custom (partitions.csv)
```

### Custom Partitions

The `partitions.csv` file allocates space for:
- Bootloader
- Application firmware
- LittleFS filesystem (for config storage)

---

## Debug Features

### Logging System

Five log levels with formatted output:

```cpp
debug("value: %d\n", x);     // [D] value: 42
info("status: OK\n");        // [L] status: OK
warn("low battery\n");       // [W] low battery
error("failed!\n");          // [E] failed!
```

### State Monitoring

```cpp
void printStateName(const char *objectName, State state) {
    Serial.printf("%s: %s | %s | %s\n", 
                  objectName,
                  getModeName(state.mode),
                  getThrowStateName(state.throwState),
                  getEntanglementStateName(state.entanglementState));
}
```

Example output:
```
stateMachine: QUANTUM | IDLE | ENTANGLED
```

---

## Future Enhancement Opportunities

1. **Multiple Entanglement**: Support >2 dice entangled simultaneously
2. **Persistent Entanglement**: Save entanglement state across power cycles
3. **Calibration Wizard**: Interactive IMU calibration sequence
4. **OTA Updates**: Over-the-air firmware updates
5. **Advanced Teleportation**: Full 3-qubit teleportation with basis selection
6. **Data Logging**: Record measurement sequences for education/analysis
7. **Web Interface**: Configuration and monitoring via WiFi AP

---

**Document Version**: 1.0  
**Last Updated**: January 2026  
**Firmware Version**: 2.0.0

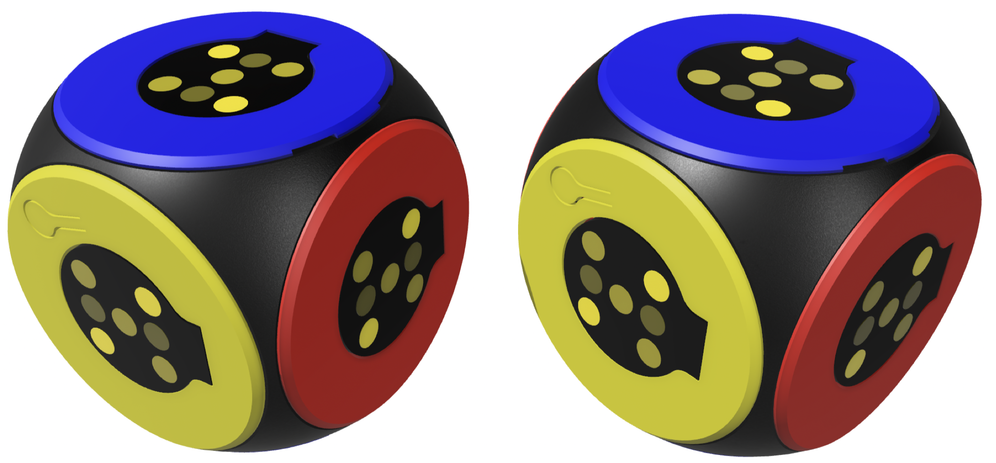
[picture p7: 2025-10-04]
images/two_dice_entangled_1.png

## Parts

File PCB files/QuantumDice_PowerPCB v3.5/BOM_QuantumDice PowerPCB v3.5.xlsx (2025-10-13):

Line # | Name | Description | Designator | Revision ID | Revision State | Revision Status | Quantity | Manufacturer 1 | Manufacturer Part Number 1 | Manufacturer Lifecycle 1 | Supplier 1 | Supplier Part Number 1 | Supplier Unit Price 1 | Supplier Subtotal 1
 | 10uF | C15850 | C1, C4, C5, C6 |  | Not managed |  | 4
 | RVT1H220M0605 | 22uF 50V 43mA@120Hz ±20% SMD, D6.3xL5.4mm Aluminum Electrolytic Capacitors - SMD ROHS C27783 RVT1H220M0605 | C2 | CMP-001-00084-2 | Draft | Up to date | 1 | Roqang | RVT1H220M0605 | Unknown
 | 100nF | C49678 | C3, C7 |  | Not managed |  | 2
 | SZYY0805W | SZYY0805W C434434 Yellow LED 5mA | D1, D2 | CMP-007-00036-1 | Draft | Up to date | 2
 | TP4056X | C2763448 | IC1 |  | Not managed |  | 1
 | TPS61200DRCT | Integrated Circuit | IC2 |  | Not managed |  | 1
 | MC14093BDR2G | Integrated Circuit | IC3 |  | Not managed |  | 1
 | Dupont SMD laying 2 pin | C5242195 | J1 | CMP-002-00080-1 | Draft | Up to date | 1
 | connector jst flat, 2 pin xh | C668620 | J2, J4 | CMP-002-00079-1 | Draft | Out of date | 2
 | StandingXH2.54JST | C146127 | J3 | CMP-002-00072-1 | Draft | Up to date | 1
 | FTC252012S2R2MBCA | 3A 2.2uH Integrated molded inductor ±20% 3.8A 1008 Power Inductors ROHS FTC252012S2R2MBCA C5832372 | L1 | CMP-006-00022-1 | Draft | Up to date | 1 | Changjiang Electronics | FTC252012S2R2MBCA | Unknown
 | 2N2222AU | 2N2222AU | Q1 | CMP-013-00034-1 | Draft | Up to date | 1
 | DMG3415U-7 | Mosfet | Q2 |  | Not managed |  | 1
 | 2.2K | C4190, 0603WAF2201T5E | R1 |  | Not managed |  | 1
 | 510R | C17734 | R2, R11 |  | Not managed |  | 2
 | 200k | C25811 | R5,R7
 | 2.2M | C325655 | R6
 | 1.8M | C3151701 | R3 | CMP-009-00178-3 | Draft | Up to date | 4
 | RL1206FR-7W0R5L | C859934 | R4 | CMP-009-00177-1 | Draft | Up to date | 1
 | 100K | C14675 | R8, R9 |  | Not managed |  | 2
 | 1K | C14676 | R10 |  | Not managed |  | 1

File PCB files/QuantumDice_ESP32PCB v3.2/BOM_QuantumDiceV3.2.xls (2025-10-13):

Comment | Designator | Footprint | JLCPCB Part #
BX-XH2.54-4PLT | J8 |  | C18077883
100pF | C6 |  | C1790
100nF | C11,C2,C13,C3,C5,C14 | CC0805KRX7R9BB104 | C49678
ESD5451N | D2,D3,D4 |  | C239604
Z- | J6,J7,J3,J2,J1,J5 |  | C262301
1uF | C7,C4 |  | C24123
USBC_RVE | J4 |  | C2765186
ATECC608A-SSHDA-B | IC3 |  | C616024
0R | R1,R13 | 0805W8F0000T5E | C17477
2.2uF | C8 |  | C19110
TS-1101-C-W | S2,S3 |  | C318938
10uF | C1,C9 |  | C15850
10k | R3,R5,R2,R4,R11,R12,R10,R6,R7,R15 | 0805W8F1002T5E | C17414
ESP32-S3-WROOM-1-N16R8 | IC1 |  | C2913202
B5819WS | D1 |  | C22624
AP2210K-3.3TRG1 | IC4 |  | C176959
5.1K | R9,R8 | 0805W8F5101T5E | C27834
0603WAF5100T5E | R14 | RC0603FR-07100RL | C23193
NCD0603G1 | LD1 |  | C84267
BNO055 | U1 |  | C93216
Q13MC1462000200 | Y1 |  | C2764505
CL10C220JB8NNNC | C10,C12 |  | C1653

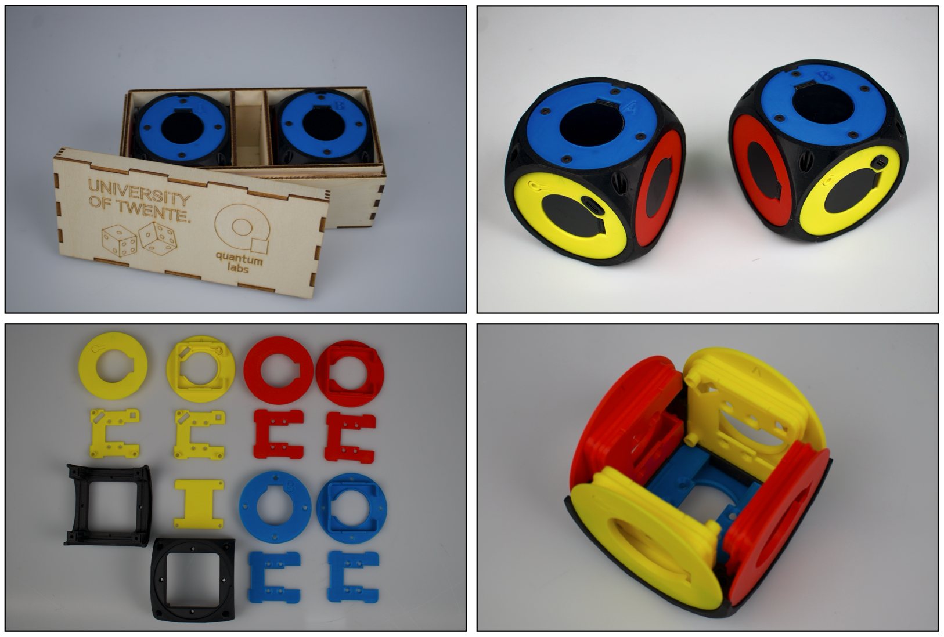
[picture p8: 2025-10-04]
images/Dice_components_1.png

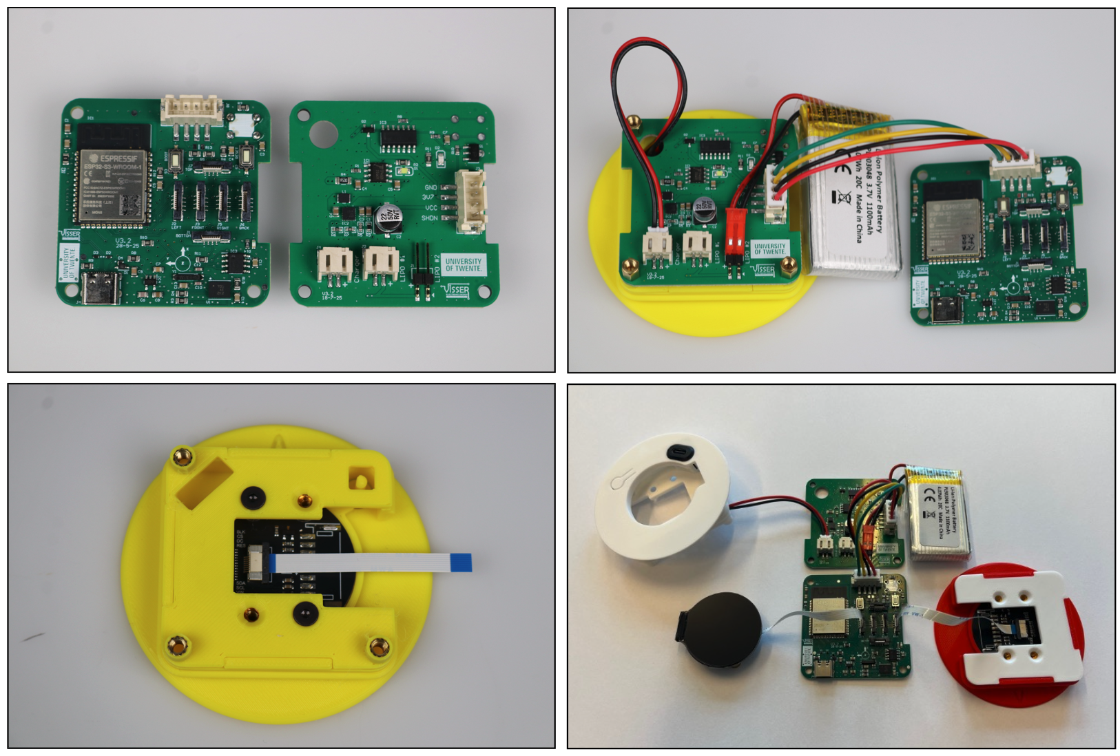
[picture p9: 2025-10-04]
images/Dice_components_2.png

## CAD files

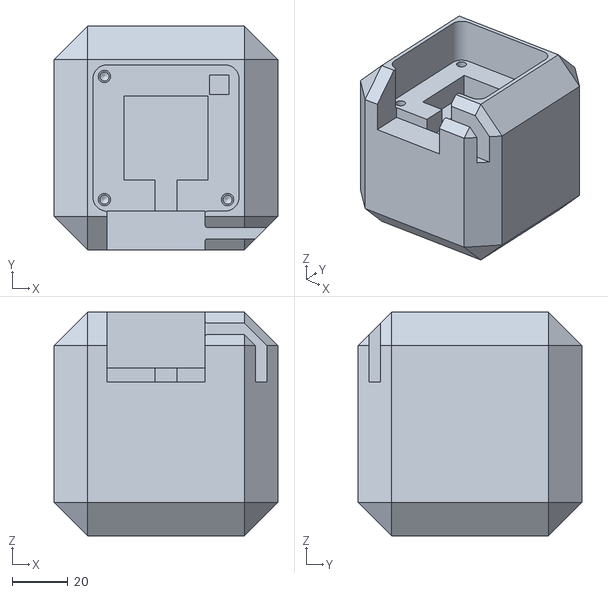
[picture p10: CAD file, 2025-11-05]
3D print files/QD IMU calibrator.stl
80.0 x 80.0 x 80.0

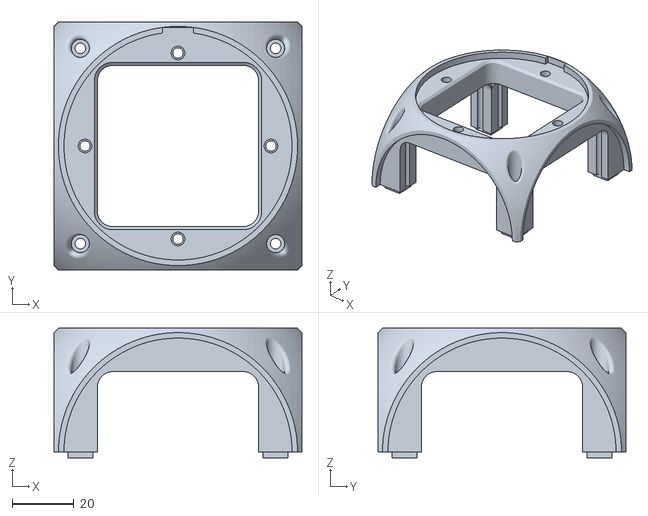
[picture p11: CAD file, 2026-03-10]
3D print files/Version 2/01A_Blck_TPU_V81_top_frame.stl
80.0 x 80.0 x 41.8

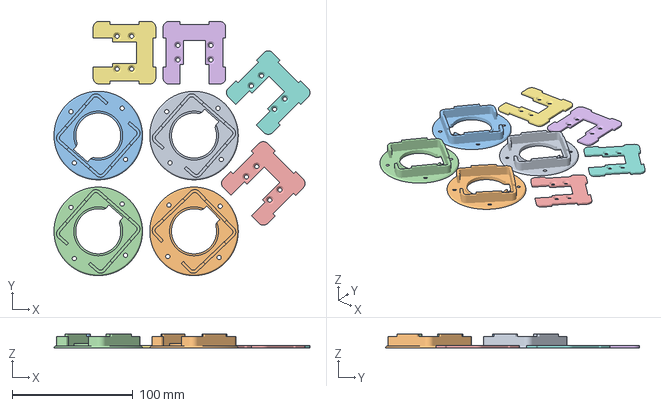
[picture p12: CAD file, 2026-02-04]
3D print files/Version 2/Blue cups bumper plate.3mf
211.7 x 210.2 x 11.6 mm
02D_Blue_PLA_V8_display_cup_bottom.stl
03A_White_PLA_V8_display_mount.stl

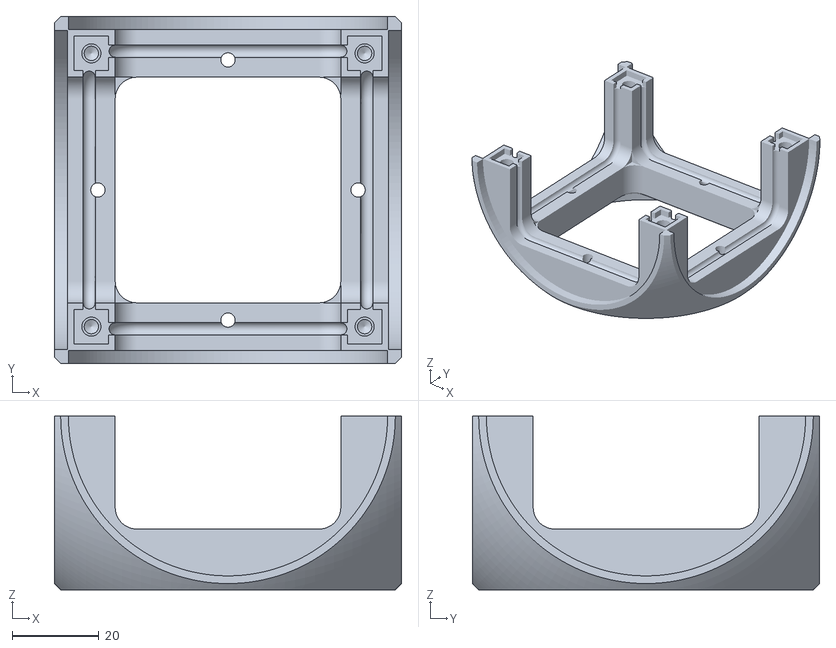
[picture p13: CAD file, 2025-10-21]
3D print files/Version 2/01B_Blck_TPU_V81_bottom_frame.stl
80.0 x 80.0 x 40.0

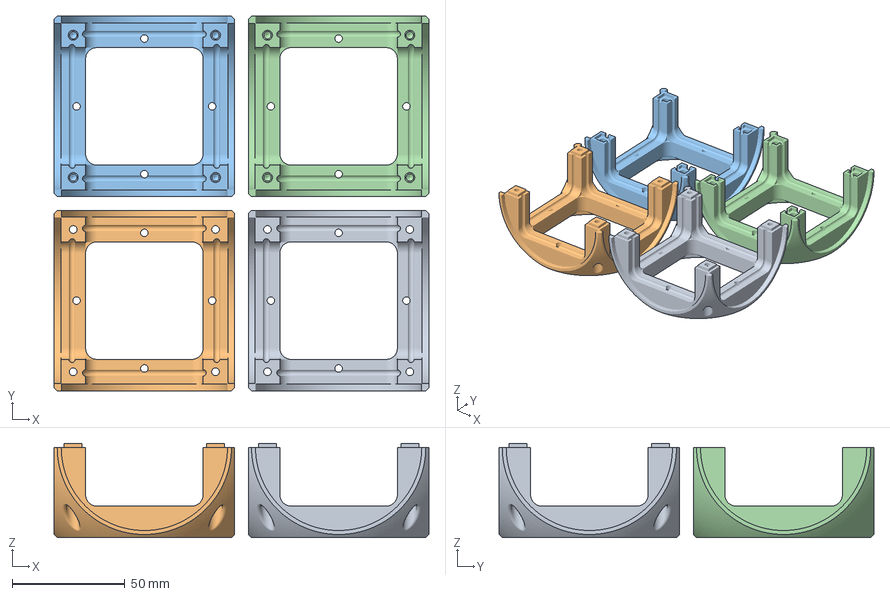
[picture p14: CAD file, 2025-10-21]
3D print files/Version 2/Frame bumper plate.3mf
166.0 x 166.0 x 41.8 mm
01A_Blck_TPU_V81_top_frame.stl
01B_Blck_TPU_V81_bottom_frame.stl

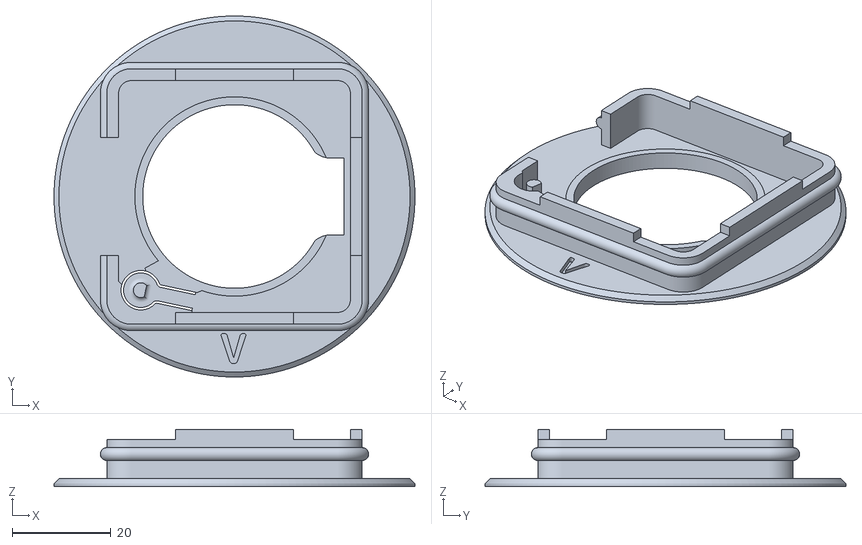
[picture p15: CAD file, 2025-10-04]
3D print files/Version 2/02B_Yellow_PLA_V8_display_cup_ESP32.stl
73.2 x 73.2 x 11.6

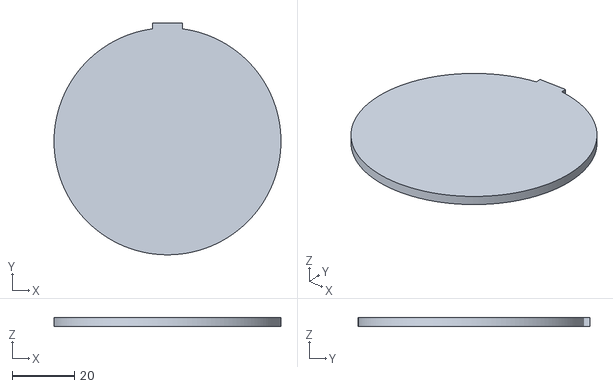
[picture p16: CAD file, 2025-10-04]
3D print files/Version 2/01C_White_PLA_V8_print_support_plate.stl
73.1 x 74.6 x 2.80

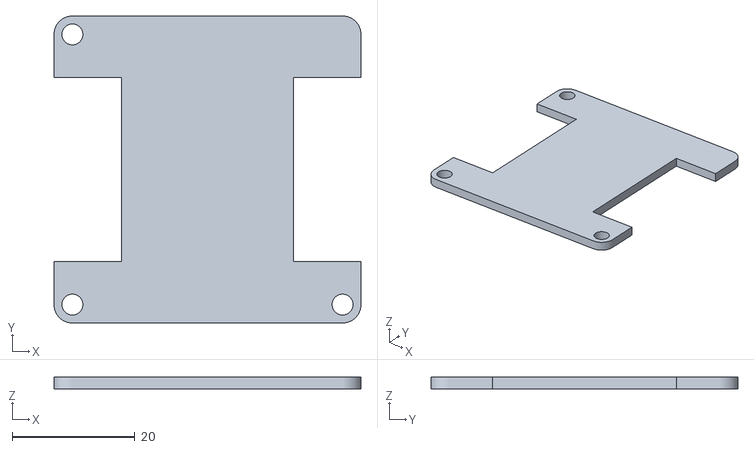
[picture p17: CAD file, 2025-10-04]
3D print files/Version 2/03C_White_PLA_V8_battery_holder.stl
50.0 x 50.0 x 2.00

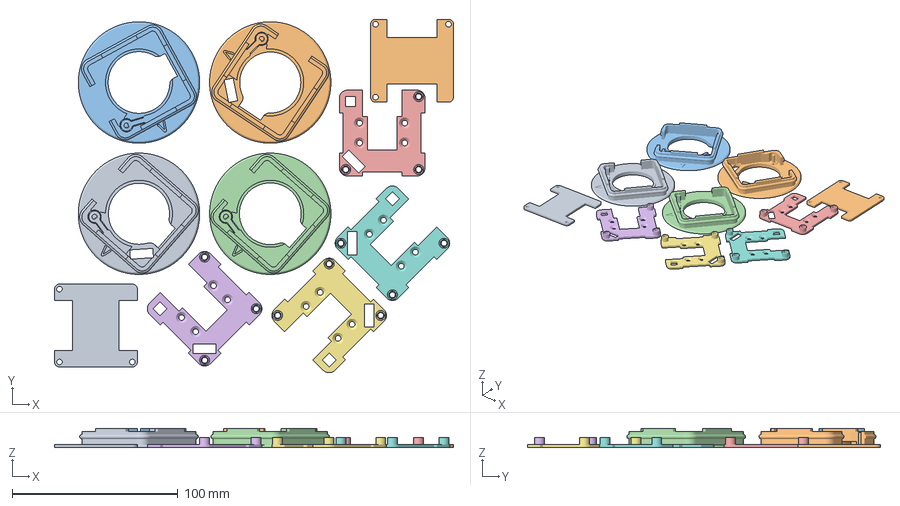
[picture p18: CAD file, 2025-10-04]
3D print files/Version 2/Yellow cups bumper plate.3mf
240.7 x 213.2 x 11.6 mm
02A_Yellow_PLA_V9_display_cup_power.stl
02B_Yellow_PLA_V8_display_cup_ESP32.stl
03B_White_PLA_V8_display_mount_PCB.stl
03C_White_PLA_V8_battery_holder.stl

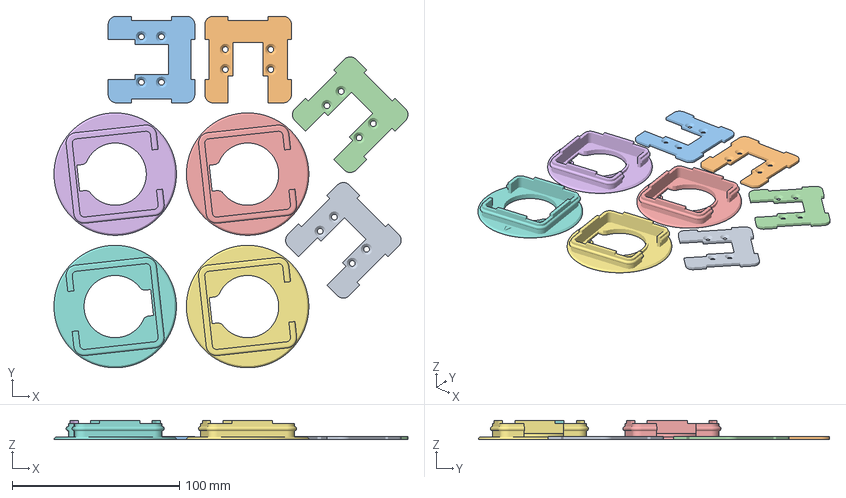
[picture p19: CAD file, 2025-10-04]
3D print files/Version 2/Red cups bumper plate.3mf
211.7 x 210.2 x 11.6 mm
03A_White_PLA_V8_display_mount.stl
02C_Red_PLA_V8_display_cup_left_right.stl

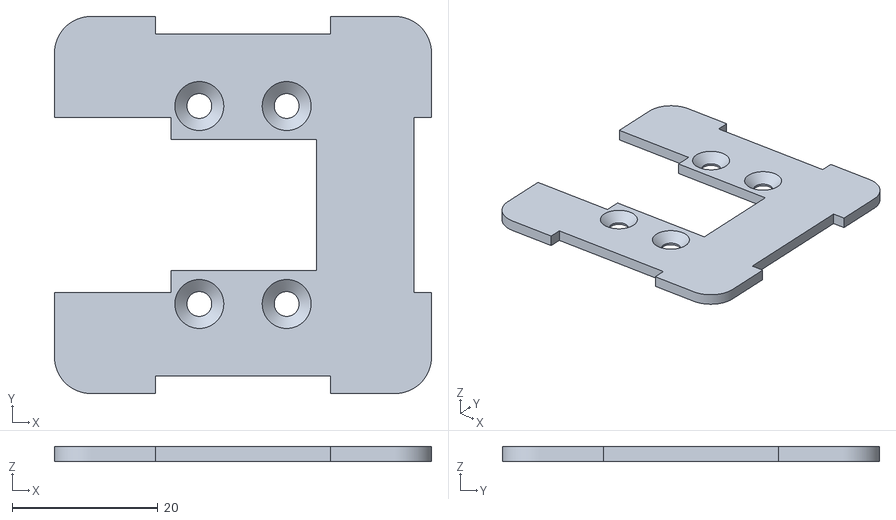
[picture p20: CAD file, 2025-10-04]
3D print files/Version 2/03A_White_PLA_V8_display_mount.stl
51.8 x 51.8 x 2.00

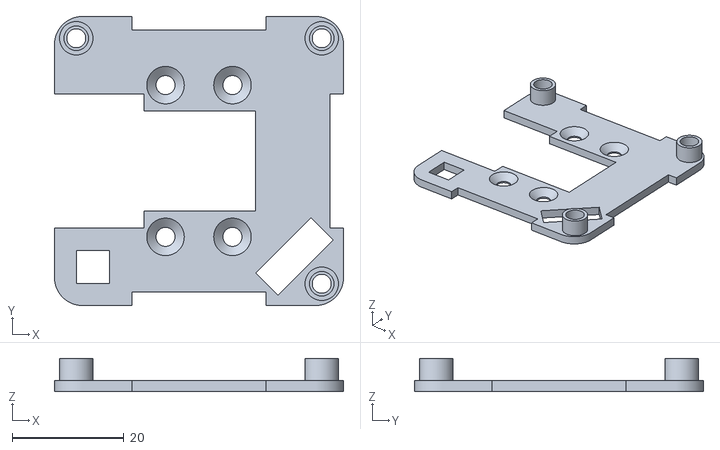
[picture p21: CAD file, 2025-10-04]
3D print files/Version 2/03B_White_PLA_V8_display_mount_PCB.stl
51.8 x 51.8 x 6.00

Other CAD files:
3D print files/Version 2/02D_Blue_PLA_V8_display_cup_top_bottom.stl
3D print files/Version 2/02C_Red_PLA_V8_display_cup_left_right.stl
3D print files/Version 2/02A_Yellow_PLA_V9_display_cup_power.stl

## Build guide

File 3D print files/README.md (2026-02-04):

> NOTE: **This instruction manuals where made for the v1.X.X version of the dice. You may need to adapt some steps for them work with the v2.X.X verion.

# QuantumDice by UTwente building the dice

In this directory you will find the 3D printfiles to build the quantum dice. Detailled [Construction and assembly manual](ConstructionManual.md).

Next to that a Bill of Material (Excel file) with both 3D print files and electronic components needed to build a set of quantum dice, including sourcing references

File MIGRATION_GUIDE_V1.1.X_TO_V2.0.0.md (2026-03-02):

# 🎲 Quantum Dice Software Migration Guide from V1.x.x. to V2.0.x

**Welcome!** This guide will walk you through updating the Quantum Dice from version 1.0.x to version 2.0.0 firmware step-by-step. Don't worry if you're not technical – we've designed this guide to be easy to follow. Just take it one step at a time, and you'll have your Quantum Dice up and running in no time!

---

## 📑 Table of Contents

1. [Why this update?](#why-this-update)
2. [What You'll Need](#what-youll-need-for-the-update)
3. [Understanding the Setup Process](#understanding-the-setup-process)
4. [Getting Started](#getting-started)
   - [Downloading the Firmware Files](#step-1-download-the-firmware-files)
5. [Installing the Main Program](#installing-the-main-program)
   - [Flashing the Quantum Dice Firmware](#step-2-flash-the-quantum-dice-firmware-to-both-dice)
   - [Preparing Your Configuration File](#step-3-prepare-your-configuration-file)
   - [Uploading Your Configuration File](#step-4-upload-your-configuration-file)
   - [Verifying Everything Works](#step-5-verify-everything-works)
6. [Troubleshooting](#troubleshooting)
7. [Need More Help?](#need-more-help)

---

## Why this update?

We are continously improving the Quantum Dice software both technical and functional. The latest release V2.0.0 is a major upgrade. Before this release a set of 2 Quantum dice were paired, meaning only a pair is able to entangle. In version 2.0.0 this is no longer the case. Any two dice in each others neigbourhood can entangle when the entanglement criteria are met. Next to that it is possible to demonstrate the Teleportation protocol. On how to do this see our Quantum Dice User Manual.

The configuration file has also changed with some new options. See an [example configuration file](https://github.com/qlab-utwente/Quantum-Dice-by-UTwente/tree/main/example_configs) for more details.

## What You'll Need for the update

Before you begin, gather these items:

### Required Items

- ✅ **Your Quantum Dice** with upper and lower displays removed
- ✅ **Computer** with internet access
- ✅ **USB-C cable** that supports data transfer (not just charging)
- ✅ **Web browser**: Chrome, Edge, or Opera (Safari and Firefox won't work)

### About Your Dice

- The USB-C connector is located on the **bottom side** of each dice
- You'll need to connect each dice **separately** during setup
- Remove the 4 wire powercable on the **upper side** of the dice before connecting the USB-C cable.

### Open Software flashing tool

- Use with Chrome, Edge, or Opera (Safari and Firefox won't work)
- go to [ESPConnect](https://thelastoutpostworkshop.github.io/ESPConnect/) - this is a generic ESP32 maintenance and software flashing tool.



---

## Understanding the Setup Process

**Don't worry – this might look like a lot, but it's simpler than it seems!**

Here's what we'll do in plain English:

1. **Download files** – Get the software files from the internet
2. **Install the main program** - Load the Quantum Dice software
3. **Upload configuration** - Put your settings on the dice
4. **Test** - Make sure everything works!

The firmware updates wil take approximitely 5 minutes per dice!

---

## Getting Started

### Step 1: Download the Firmware Files

**What you're doing:** Getting the software programs that run your Quantum Dice.

1. **Open your web browser** and go to:  
   [https://github.com/qlab-utwente/Quantum-Dice-by-UTwente/releases/](https://github.com/qlab-utwente/Quantum-Dice-by-UTwente/releases)

2. **Look for the latest release** at the top of the page (it will have a version number like v2.0.0)

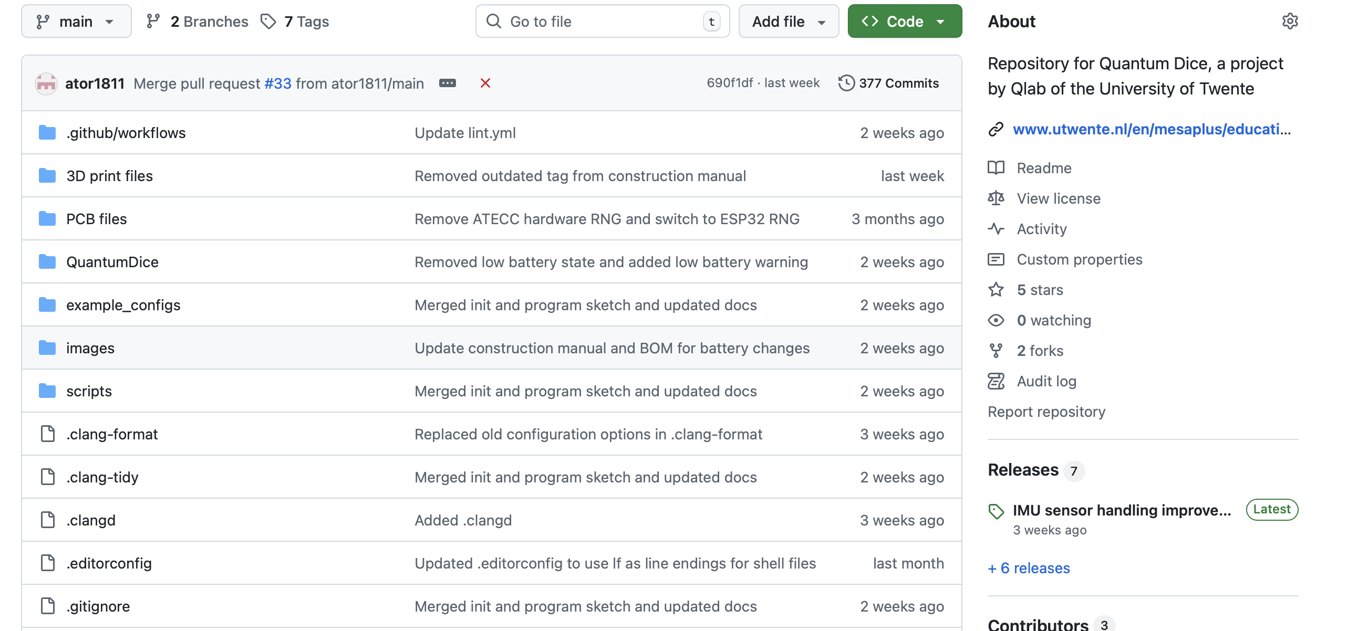
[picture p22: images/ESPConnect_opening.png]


1. **Download the files:**
   - `QuantumDice.vX.X.X.merged.bin` – (X.X.X will be version numbers)
   - (`QuantumDice.vX.X.X.merged.bin` is not needed now)

✅ **You're done with Step 1!**

---

## Installing the Main Program

### Step 2: Flash the Quantum Dice Firmware to Both Dice

**What you're doing:** Installing the main Quantum Dice program the dice.

**With your dice connected:**

1. **Open [ESPConnect](https://thelastoutpostworkshop.github.io/ESPConnect/)** with Chrome, Edge, or Opera (Safari and Firefox won't work)

2. **In ESPConnect, click Connect, select the COM-port of the ESP32**



1. **In ESPConnect, click "Flash Tools"** in the left sidebar

2. **Scroll to the "Flash Firmware" section**



1. **Click "Firmware binary (.bin)" button**

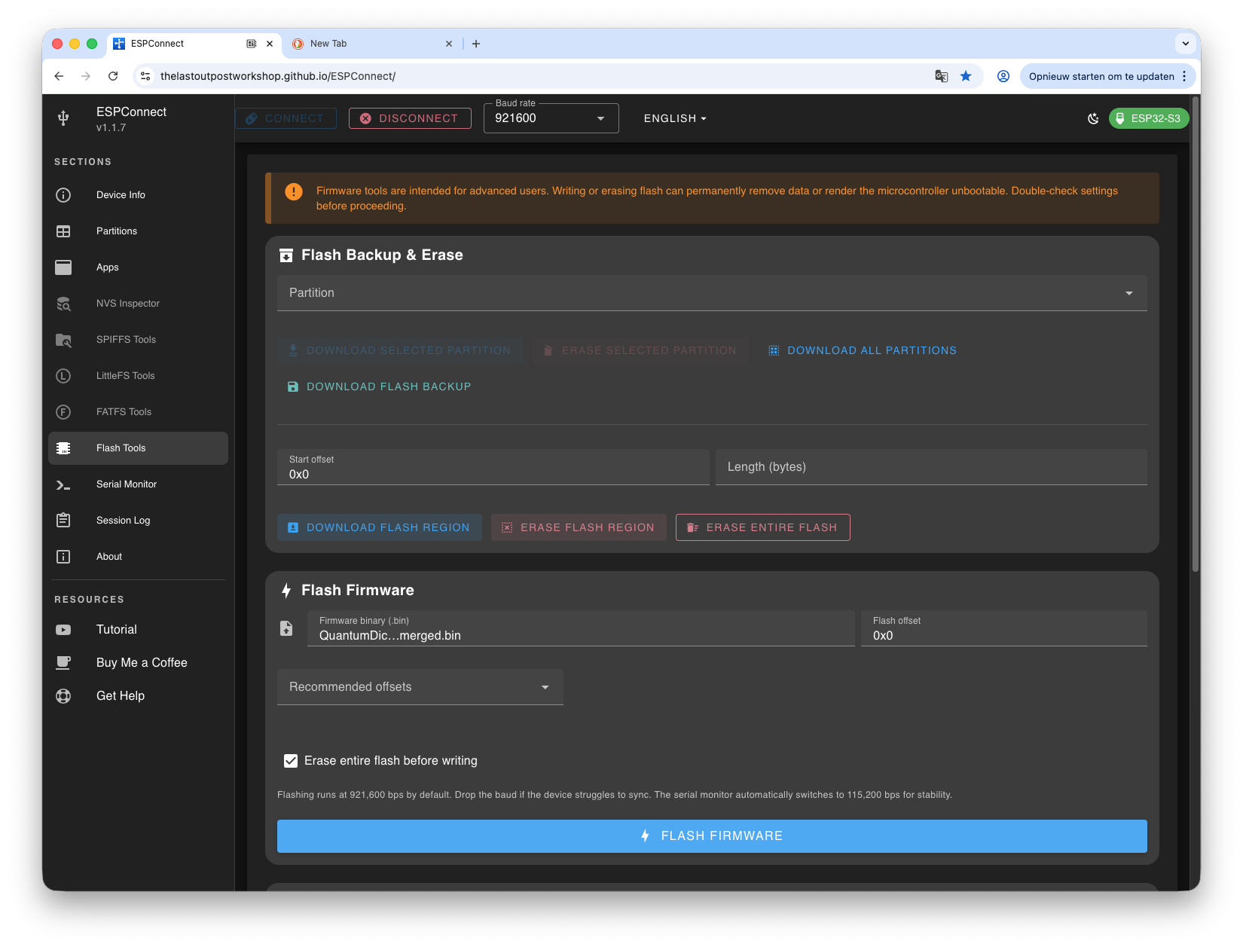
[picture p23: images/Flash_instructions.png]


1. **Select the file** `QuantumDice.vX.X.X.merged.bin` (from Step 1)

2. **Select Flash Offset on 0x0**

3. **Check "Erase entire flash before writing"**

4. **Click "⚡ Flash firmware"** and confirm

5. **Wait** for the upload to complete (about 30 seconds to 1 minute)

6. **Success!** You should see "Flash complete"

7. **Repeat for all your dice:**
    - Disconnect the current dice
    - Connect the next dice
    - Follow the same steps (steps 1-7 above)

✅ **Quantum Dice firmware is now installed on all dice!**

---

### Step 3: Prepare Your Configuration File

**What you're doing:** Creating a file that tells your dice how to behave.

1. **Download the example configuration file:**  
   [TEST1_config.txt](TEST1_config.txt) *(right-click and "Save Link As...")*

2. **Open the file** your text editor

3. **Read the instructions** inside the file – they explain what each setting does

4. **Search for `diceId=TEST1` and change this to you own diceID** – the diceID appears on the display during startup. Your're free to choose any character

5. **Adjust the other settings if needed** (colors, timeouts, etc.) – the default values work well for most users

6. **Save the file** with your new name:
   - Save it as `YOURNAME_config.txt`

✅ **You're done with Step 3!**

### Step 4: Upload Your Configuration File

**What you're doing:** Putting your configuration settings onto your dice.

**Make sure your dice is still connected.**

1. **In ESPConnect, click "LittleFS Tools"** in the left sidebar

2. **Click "Download Backup"** button
   - This is a safety step required before uploading
   - Even if there's nothing to back up, click it anyway
   - Wait for it to complete

3. **After the backup completes**, the "Upload File" section will become available

4. **Click "Choose File"**

5. **Select your configuration file** (e.g., `YOURNAME_config.txt`)

6. **Click "Upload"** – the file uploads to your browser only (not to the dice yet!)

7. **Click "SAVE TO FLASH"** button

8. **Confirm** when asked (click "OK" or "Yes")

9. **Wait** for the upload to complete

10. **Verify the upload:**
    - Look for the eye icon next to your file
    - Click it to view the contents
    - Make sure it matches your configuration file

✅ **Configuration uploaded your dice!**

---

### Step 5: Verify Everything Works

**What you're doing:** Making sure your dice are working correctly.

#### Method 1: Visual Test (If Displays Are Connected)

1. **Watch for the startup sequence:**
   - You should see logos and animations
   - The dice should display properly

✅ **If you see the startup sequence, your dice are working!**

#### Method 2: Serial Monitor Test

**This method works even without displays attached.**

1. **Connect a dice to your computer**

2. **In ESPConnect, click "Serial Monitor"** in the left sidebar

3. **Click "Start"** button

4. **Watch the text output** – you should see something like:

```text
   [LOG] 
   [LOG] ╔════════════════════════════════════════╗
   [LOG] ║      QUANTUM DICE INITIALIZATION       ║
   [LOG] ╚════════════════════════════════════════╝

   [LOG] /home/twan/Development/Quantum-Dice-by-UTwente/QuantumDice/QuantumDice.ino Jan 26 2026 21:09:54
   [L] FW: 2.0.0
   [LOG] Step 1: Initializing filesystem and configuration...
   [LOG] 
   [DEBUG] Mounting LittleFS...
   [DEBUG] LittleFS mounted successfully
   [D] Total: 4194304 bytes, Used: 8192 bytes
   [D] Found config file: YOURNAME_config.txt
   ...
```

1. **What to look for:**
   - ✅ "Config loaded successfully"
   - ✅ "LittleFS mounted successfully"
   - ✅ "ESP-NOW initialized successfully"
   - ✅ Your dice ID appears correctly
   - ⚠️ You might see some I2C error messages – these are usually okay if sensors initialize afterward

✅ **If you see "Setup complete!" you're all done!**

---

## Troubleshooting

### "WebSerial API is not supported"

**What this means:** Your browser doesn't support the tool we need.

**Solutions:**

- ✅ Switch to Chrome, Edge, or Opera browser
- ✅ Update your browser to the latest version
- ❌ Safari and Firefox don't work – you must use Chrome, Edge, or Opera

---

### "Cannot connect to serial port" or "Port is not available"

**What this means:** Something is blocking access to your dice.

**Solutions:**

- ✅ Close Arduino IDE, PuTTY, or any other program that might be using the port
- ✅ Disconnect and reconnect your USB cable
- ✅ Try a different USB port on your computer
- ✅ Try a different USB-C cable (some cables are charge-only)
- ✅ Restart your computer if the problem persists

**To check if your computer sees the device:**

- **Windows:** Open Device Manager → look under "Ports (COM & LPT)"
- **Mac:** Open Terminal → type `ls /dev/tty.*` and press Enter
- **Linux:** Open Terminal → type `ls /dev/tty*` and press Enter

---

### "Flash failed" or "Upload failed"

**Solutions:**

- ✅ Check your USB cable – make sure it supports data transfer
- ✅ Try holding the BOOT button on your dice while clicking "Flash firmware"
- ✅ Make sure Flash Offset is set correctly:
  - `0x0` for initial upload with the `vX.X.X.merged.bin` file
  - `0x10000` for software updates with the `vX.X.X.bin` file
- ✅ Try a different USB port
- ✅ Make sure no other program is using the serial port

---

### Configuration File Not Loading

**Signs:** Serial monitor shows "No config file found" and creates and uses `DEFAULT_config.txt`.

**Solutions:**

- ✅ Make sure your filename matches the pattern: `XXXXX_config.txt` (5 letters before _config.txt)
- ✅ Check that Flash Offset was `0x10000` when you flashed the main firmware
- ✅ Try uploading the config file again ([Step 4](#step-4-optional-upload-your-configuration-file))
- ✅ Use the eye icon in LittleFS Tools to verify the file is actually on the dice

---

### Dice Show Errors on Serial Monitor

**I2C Errors:**

```
E (3535) i2c.master: I2C transaction unexpected nack detected
```

These are usually **normal** if you see "BNO055 initialization complete!" afterward. The sensors are just taking a moment to respond.

**Real Problems to Watch For:**

- ❌ "LittleFS mount failed" – means storage wasn't set up properly, try flashing the firmware again with the merged.bin file
- ❌ "Config load failed" – means your config file has errors or wasn't uploaded
- ❌ Setup never completes – check all previous steps

---

## Need More Help?

If you're stuck:

1. **Double-check you followed each step** – it's easy to miss something small!

2. **Look at the serial monitor output** – it often tells you exactly what's wrong

3. **Try the process on the other dice** – sometimes one dice has an issue but the other works fine

4. **Reach out for support:**
   - Check the GitHub repository for updates: [https://github.com/qlab-utwente/Quantum-Dice-by-UTwente](https://github.com/qlab-utwente/Quantum-Dice-by-UTwente)
   - Create an issue on GitHub with:
     - What step you're on
     - What error message you see
     - What you've already tried

---

## 🎉 Congratulations

You've successfully set up your Quantum Dice! The hard part is done. From now on, updates are quick and easy.

**Enjoy your Quantum Dice!** 🎲

---

*Document Version 1.1 – Last Updated: February 2026*

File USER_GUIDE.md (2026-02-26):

# Quantum Dice User Manual

## Table of Contents

1. [Introduction](#introduction)
2. [Power On](#power-on)
3. [Charging the Battery](#charging-the-battery)
4. [Start Up Sequence](#start-up-sequence)
5. [Basic Quantum State](#basic-quantum-state)
6. [Using the Quantum Button](#using-the-quantum-button)
7. [Entanglement](#entanglement)
8. [Teleportation](#teleportation)

---

## Introduction

Once your Quantum Dice assembly is complete, you're ready to start using it! This manual covers:

- Powering the device on and off
- Understanding the startup sequence
- Using the Quantum button
- Entangling two quantum dice
- Charging the battery

**Device orientation:** The dice has 3 axes, color-coded as follows:

- **Blue** - top and bottom sides
- **Red** - left and right sides
- **Yellow** - front and rear sides
Watch the [instructional video](https://youtu.be/DUJu3AJgXRc?si=qqh9P63NLDmi5nQ0) for usage guidance

---

## Power On

Locate the power button on one of the yellow sides (marked with a power symbol).

**To power on/off:** Press the button briefly.

---

## Charging the Battery

**Battery specifications:**

- Capacity: 1800 mAh
- Charging current: 500 mA

**Charging instructions:**

1. Locate the USB-C connector on one of the yellow sides
2. **⚠️ Important:** This connector is **only** for battery charging and is not connected to the ESP32 processor
3. **Use a USB-A to USB-C cable** with a USB-A charger (USB-C chargers will not work)
4. Charging takes approximately **2-3 hours**

**Monitoring charging status:**

The charge indicator LEDs are located inside the dice and are not visible during charging. To monitor the charging process, you can use:

- A USB charger with a built-in current indicator, or
- A USB current monitor dongle such as [this one](https://www.amazon.com/Multi-function-Voltmeter-Electrical-Appliances-Detection/dp/B0CRTBWTQF?th=1)

---

## Start Up Sequence

After powering on, the dice initializes and displays the following:

1. **Qlab logo** followed by additional branding
2. **Device information** on the power button display:
   - Dice ID
   - Firmware version
   - Battery voltage

**⚠️ Low battery warning:** If the battery voltage is low, charge the device before use. See [Charging the Battery](#charging-the-battery)

The startup sequence completes in **Classic mode**, where each side displays a fixed number (like a traditional die). Long press the Quantum button to enter Quantum mode.

---

## Basic Quantum State

In Quantum mode, all six sides display a **superposition state**.

**How it works:**

- Roll the dice
- When it comes to rest, a random number appears on the top and bottom sides
- This represents the "measurement" of the quantum state

---

## Using the Quantum Button

The Quantum button is located on the opposite side from the power button.

**Short press:** Toggle entanglement colour display
**Long press:** Return to Classic mode

### Entanglement Colour Display

When two dice are entangled, the Quantum Dice will display colours on the superposition state to indicate entanglement status. Both dice will have the same colour. When the colour display is toggled off, the dice will show the entanglement colour, and shortly after revert to the standard superposition state display.

---

## Entanglement

**Requirements:** Both dice must be in Quantum mode.

**How to entangle:**

1. Ensure both dice are in Quantum mode (superposition state visible)
2. Bring the two dice close together
3. You may need to adjust their position slightly
4. **Success indicator:** The superposition state turns **coloured**

**After entanglement:**

- Roll both dice separately
- The measurement outcomes will be **correlated** between the two dice
- After measurement, each die returns to its previous state

**⚠️ Important:** After entanglement, separate the dice by **more than 1 meter** to prevent them from re-entangling after rolling.

---

## Teleportation

**Requirements:** Three dice in Quantum mode, here called A, B, and M.

**How to teleport:**

1. Entangle Dice A and Dice B
2. Bringt Dice M into the disired quantum state (either superposition, mearsured state, or entangled state with another die)
3. Place Dice M close to Dice A to perform the teleportation operation
4. **Success indicator:** Dice B will now reflect the quantum state of Dice M
    - If Dice M was in superposition, Dice B will now be in superposition
    - If Dice M was measured, Dice B will show the same measurement outcome **when rolled in the same basis**
    - If Dice M was entangled with another die, Dice B will now be entangled with that die

### Entangelemnt Colour Display with Teleportation

When teleportation is successful, Dice B will display the entanglement colour of Dice A and M. If the colour display is toggled off, Dice B will show the entanglement colour briefly before reverting to the standard superposition state display.

---

**Enjoy your Quantum Dice!**

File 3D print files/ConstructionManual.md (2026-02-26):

## 1. Introduction

This construction manual provides all the information required to build your own set of **Quantum Dice**. It includes component sourcing, 3D printing, and step-by-step assembly instructions.

The Quantum Dice were developed by the **University of Twente**. All designs are freely available under the **CC BY licence**.

For further information, visit [Quantum Dice by University of Twente](https://www.utwente.nl/en/mesaplus/education/quantum-dice/) or read the pre-print of our article on [arXiv](https://arxiv.org/abs/2510.04931).

---

## 2. General description of the Quantum Dice

The Quantum Dice are designed to make abstract quantum-mechanical concepts such as **Quantum Superposition**, **Entanglement**, and **Quantum Key Distribution** more tangible.

The dice are used in pairs. Both share identical software and 3D-printed parts.

Each Quantum Die consists of a **3D-printed frame** with electronic displays on all six sides. The displays are driven by a **microcontroller unit (MCU)** – an **ESP32-S3** module equipped with an orientation sensor and a random generator. Power is supplied by a rechargeable battery.

The base of the Quantum Die is a **black frame** holding six **TFT displays**, each mounted in a *display cup*.  
The display cup colour indicates its orientation axis:

- Front / Rear → **x-axis** → yellow  
- Top / Bottom → **z-axis** → blue  
- Left / Right → **y-axis** → red  

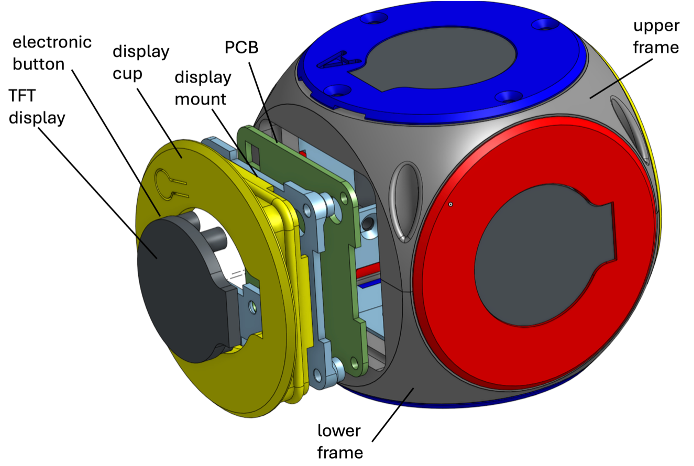
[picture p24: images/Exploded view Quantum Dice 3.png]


The ESP32 module is soldered to a **Printed Circuit Board (PCB)** referred to as the **ProcessorPCB**.  
This board also carries:

- connectors for the six displays  
- an **Inertial Measurement Unit (IMU)** to detect physical orientation and motion  
- a **cryptographic chip**  
- a **push-button**  

The ProcessorPCB is mounted on the **rear (yellow) display cup**.

To power the system, a second PCB – the **PowerPCB** – is mounted on the **front (yellow) display cup**.  
It provides power to the ProcessorPCB via a **four-wire cable** and includes:

- a **battery connector**  
- a **power on/off button**  
- a **voltage regulator**  
- a **charging circuit** with a **USB-C connector**

The MCU monitors the battery voltage continuously.



---

## 3. Sourcing of Materials

All parts required to construct the Quantum Dice are listed in the **Bill of Materials (BOM)**.  
The BOM can be found here: [BOM](/3D%20print%20files/Bill%20of%20Material%20quantum%20dice.xlsx).

It is an Excel sheet containing all components and quantities. At the top of the sheet, you can specify the number of die you wish to build. The total quantities will update automatically.

---

### 3.1 Quantum Dice Versions

Not applicable anymore

---

### 3.2 Sourcing Electronic Components

#### PowerPCB and ProcessorPCB

The **PowerPCB** and **ProcessorPCB** can be obtained directly from the University of Twente:  
[Quantum Dice by University of Twente](https://www.utwente.nl/en/mesaplus/education/quantum-dice/).

The ProcessorPCB is supplied pre-configured with the latest firmware, including **IMU calibration** and **functional testing**.  
Each board is labelled with its **MAC address** (on the rear side) and its assigned **role (A or B)**.

A set of **connection cables**, **screws**, and **bolts** is included.

Alternatively, if you have experience with microcontroller software and PCB design, you can order the PCBs yourself and flash the software manually.

- PCB fabrication files: [PCB fabrication files](../PCB%20files/)
- Arduino sketches can be downloaded [here](/Arduino/QuantumDice/)

---

#### Displays and Battery

The links to obtain the TFT displays are included in the **BOM file**.

Links for sourcing **LiPo batteries** are also included, although availability may vary.  
If a listed supplier is unavailable, equivalent alternatives can be used.

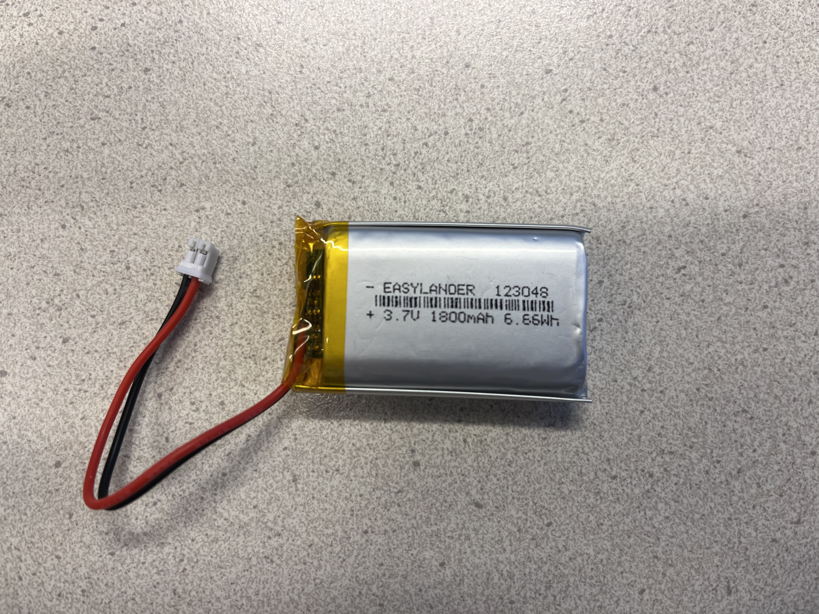
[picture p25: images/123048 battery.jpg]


**Battery specifications:**

- **Type:** 3.7 V LiPo  
- **Protection:** Built-in protection circuit (hidden under the black tape in the image above)  
- **Capacity:** ~ 1700 mAh  
- **Dimensions:** Maximum height 48 mm, width 35 mm. Thickness typically 9–12 mm (depending on capacity)  
- **LiPo Code:** e.g. *903048* → 9 mm thick, 30 mm wide, 48 mm high  
- **Connector:** JST-PH 2.0

---

#### Flat cable and wire set

The following cables are required, as illustrated in the figure below:
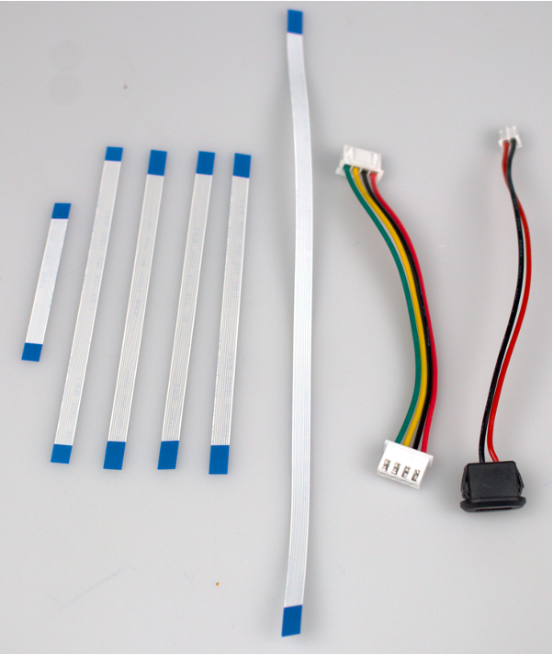
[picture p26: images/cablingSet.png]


From left to right:

- FFC flat cable (various lengths available) for connecting the displays to the ProcessorBoard
- 4-wire power cable for connecting the PowerBoard to the ProcessorBoard
- USB-C charging cable for connecting to the PowerBoard

Detailed specifications and sourcing information are available in the BOM. UTwente can supply a complete cable set with the ProcessorBoard and PowerBoard

---

## 4. Sourcing 3D-Printed Parts

### 4.1 Printing with TPU

Printing **TPU (Thermoplastic Polyurethane)** requires special care.

1. **Dry the filament** before use to avoid stringing.  
2. **Reduce printing speed**, particularly on fast printers like the Prusa Core One or Bambu Lab models.  
3. TPU **cannot be used** with Bambu Lab’s **AMS system** or Prusa’s **MMU3** because these systems push filament into the print head. TPU must instead be **pulled** due to its elasticity.

A hardness of **95A** or **40D** is recommended.

**Examples of TPU suppliers:**

- [TPU 95A HF](https://eu.store.bambulab.com/products/tpu-95a-hf) – available in multiple colours.  
- [Fiberlogy Fiberflex-40D](https://www.3djake.nl/fiberlogy/fiberflex-40d) – limited colour options; system preset available for Prusa3D (reduce print speed to ~60%).

For more details on TPU printing:

- [Bambu Lab TPU Printing Guide](https://wiki.bambulab.com/en/knowledge-sharing/tpu-printing-guide)
- [How to Improve TPU Print Quality on Bambu Lab X1 Carbon (YouTube)](https://youtu.be/yN3RximKNiE?si=DYWy9xm7ewkI_fWw)

If printing TPU yourself is not practical, you can **outsource the job**.  
Several companies offer TPU printing services. The **price** mainly depends on the **printing method**:

- **Fused Deposition Modelling (FDM):** cheaper  
- **Selective Laser Sintering (SLS):** higher quality but more expensive  

Recommended supplier (based on experience):  
[JLC3D FDM Printing](https://jlc3dp.com/3d-printing/fused-deposition-modeling) – good quality at reasonable cost.

---

### 4.2 3D-Printed Components

All 3D models are supplied in **STL format**.  
Filenames include the **colour**, **material**, and a **version number**.

Each Quantum Die consists of the following printed components:

#### Display Cups (for mounting TFT displays)

- Three colour variants for the X, Y, and Z axes.  
- Each cup requires a **backplane** that must be **glued** onto it.  
- The **yellow backplanes** (front and rear) differ from the others, as they are designed to hold the **PowerPCB** and **ProcessorPCB**.  
- An additional backplane is used to mount the **battery**.  
- **No support** is required for printing these parts.

#### Upper and Lower Frame Parts (black)

- Printed flat-side down on the print plate.  
- **Supports are required** for these components.

#### Selecting Parts

In the provided **Excel sheet**, fill in the number of dice required for roles A and B.  
The sheet will calculate which 3D files and electronic parts are needed.

For convenience, **3MF build plates** containing all required parts are included.  
These were created using **PrusaSlicer**, but they can also be used in **Bambu Studio**.  
Minor rearrangements of parts may be necessary.

---

## 5. Assembly of 3D-Printed Parts

### 5.1 Introduction

The following instructions describe the assembly of **one Quantum Die**.  
If you are building a pair of dice, you will need to follow this procedure **twice**.

---

### 5.2 Required Tools

In addition to the Quantum Dice components themselves, you will need the following tools:

- Soldering iron  
- Screwdrivers hex key (2 mm and 2,5 mm)  
- Cutting pliers  
- CA-glue e.g. LOCTITE 406 for plastics
- Double sided foam tape

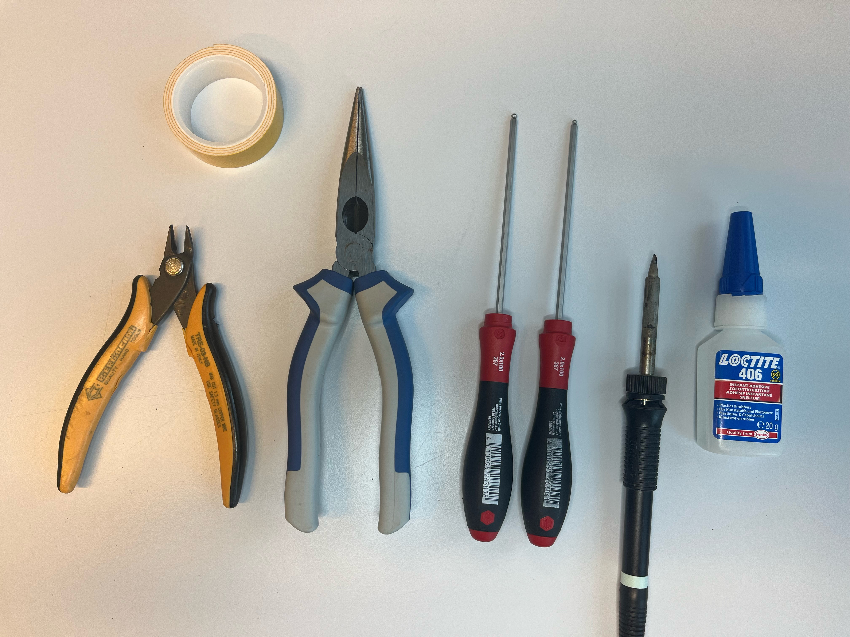
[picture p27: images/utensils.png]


---

### 5.3 3D-Printed Components per Die

For each Quantum Die, print the following components (see figure [x]):

- 1 × black **top frame**  
- 1 × black **bottom frame**  
- 2 × yellow **display cups** + 2 × yellow **display backplanes**  
- 2 × red **display cups** + 2 × red **display backplanes**  
- 2 × blue **display cups** + 2 × blue **display backplanes**  
- 1 × **battery mount**

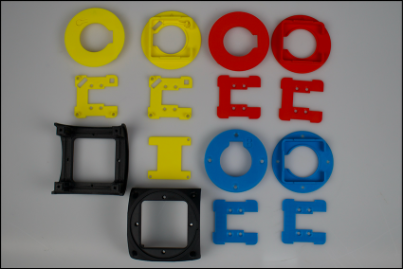
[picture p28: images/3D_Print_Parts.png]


> **Note:** The design of the display backplanes differs per colour. The yellow ones have additional mounting features for the PCBs.

---

### 5.4 Mounting the Charger Cable

Insert the **USB-C charging connector** firmly into the opening of the designated **yellow display cup**.  
A small amount of pressure may be required to click it into place.

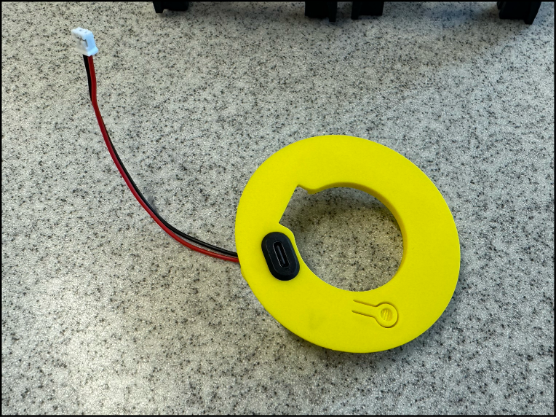
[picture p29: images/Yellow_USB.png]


---

### 5.5 Installing Threaded Inserts

After printing all components, **threaded inserts** must be installed in several parts. These inserts are used for screwing the dice together securely.

Threaded inserts are required in:

- the **black frame**, and  
- both **yellow display cups**

**Procedure:**

1. Place each insert into its designated hole with the **smooth side facing outwards**. The insert should initially sit about one-third deep.  
2. Touch the insert gently with a **heated soldering iron**.  
3. Apply slight downward pressure so that the insert melts into the plastic until it sits flush with the surface (see figure).  

Allow the plastic to cool completely before continuing.

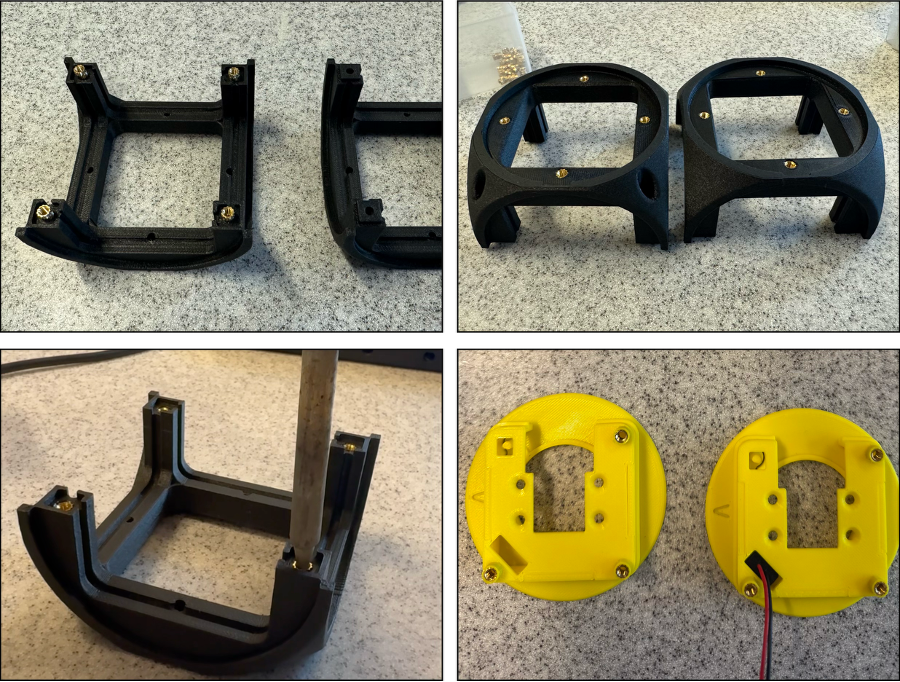
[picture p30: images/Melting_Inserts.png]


---

### 5.6 Gluing the Backplanes

Attach the **backplanes** to their respective **display cups** using **cyanoacrylate (CA) glue** such as *Loctite 406 for plastics*.

**Instructions:**

- Apply only a few drops of glue to the recessed edge of the display cup.  
- Avoid excess glue, as it may overflow and permanently bond parts that should remain separate.  
- Press the backplane firmly in place and allow it to cure.

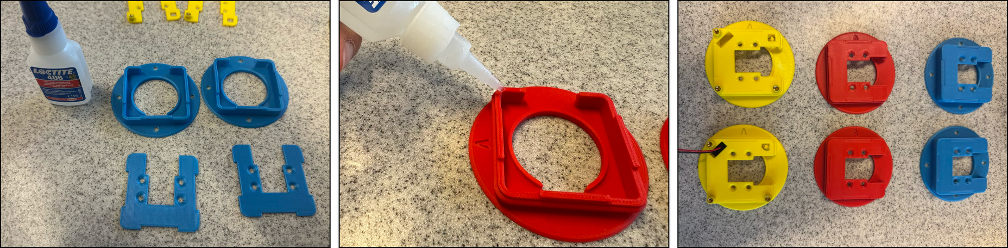
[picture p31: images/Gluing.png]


---

## 6. Preparing Electronic Parts and Displays

### 6.1 Introduction

This section describes the preparation of the electronic components before assembly.  
If you sourced pre-assembled boards from the **University of Twente**, some steps (such as soldering) may be skipped.

---

### 6.2 Materials and Required Tools

- ProcessorPCB  
- PowerPCB  
- Six TFT displays  
- FPC cables (flat ribbon cables)  
- Battery and charger cables  
- M3 screws and threaded inserts  

---

### 6.3 Soldering Push Buttons  

*(Skip this step if electronics were sourced from the University of Twente.)*

Solder the push buttons onto both the **PowerPCB** and **ProcessorPCB** as indicated in the circuit diagram.  
Ensure clean solder joints and avoid overheating the components.

---

### 6.4 Removing Display Connectors

*(Skip this step if displays were sourced from the University of Twente.)*

Before the TFT displays can be mounted in their cups, the **grey plastic connectors** (and their pins) on the displays must be removed.  
This is necessary because alternative connectors will be used later.

**Procedure:**

1. Use a **pair of cutting pliers** to make two cuts along the sides of the grey connector housing.  
   This will release the plastic frame from the display board.  
2. Grip the connector firmly with pliers and gently rock it back and forth along its short side until it detaches, bringing the metal pins with it.  
   The displays can withstand moderate force.  
3. Remove any **protective foil stickers** covering the screw holes so the displays can later be mounted into the cups.

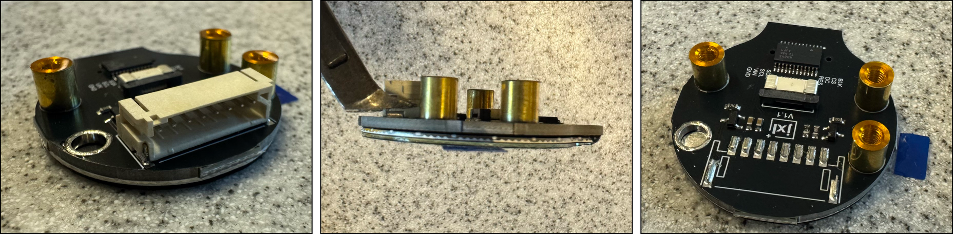
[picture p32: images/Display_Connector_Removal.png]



---

### 6.5 Mounting Displays into Display Cups

1. Insert each display into the back of its display cup. Some pressure may be needed.  
   If a display does not fit properly due to a slightly protruding edge, carefully sand the plastic with fine sandpaper.  
2. Fix the displays in place using **black countersunk M3×6 screws**.  
3. Test-fit the **yellow** and **red** display cups into the **lower black frame** to verify alignment.  

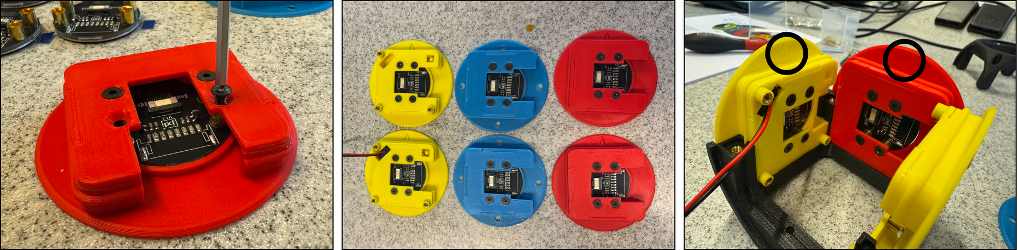
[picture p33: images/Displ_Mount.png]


> **Note:**  
> On the inside of each yellow and red display cup you will find a “^” symbol. This symbol must always point **upwards** when mounted in the frame.

---

## 7. Assembling the Quantum Die

### 7.1 Introduction

This final section describes how to assemble all components, attach the cables, mount the **ProcessorPCB** and **PowerPCB**, and complete the housing of the Quantum Die.

---

### 7.2 Connecting FPC Cables to FPC Connectors (Sliding-Latch Type)

Before connecting all displays, it is important to understand how to attach the **FPC cables** (flat ribbon cables) correctly to the **FPC connectors**.  
Locking and unlocking these connectors can be delicate, so follow the instructions carefully.

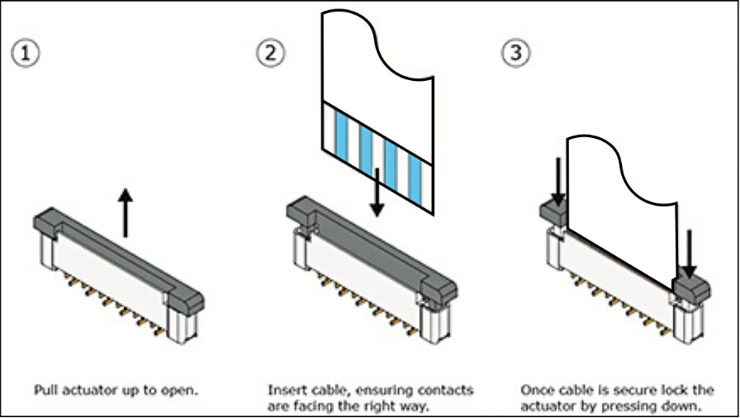
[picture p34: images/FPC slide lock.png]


#### Steps

1. **Unlock the connector**  
   On the back of each display there is a small FPC terminal.  
   Gently pull the **sliding latch** into the *open position*.  
   Do not apply excessive force.

2. **Insert the FPC cable**  
   Align the **contact side** of the FPC cable with the connector terminals.  
   When inserting, ensure that the **blue side** of the cable faces upwards – this is also the side with the small notch on the connector.  
   Carefully slide the cable straight in until it stops.

3. **Lock the connector**  
   Push the sliding latch back into the *closed position* to secure the cable.  
   Check that the cable remains fully inserted during this step.

4. **Verify the connection**  
   Confirm visually that the **blue marking** on the FPC cable is flush with the connector housing.

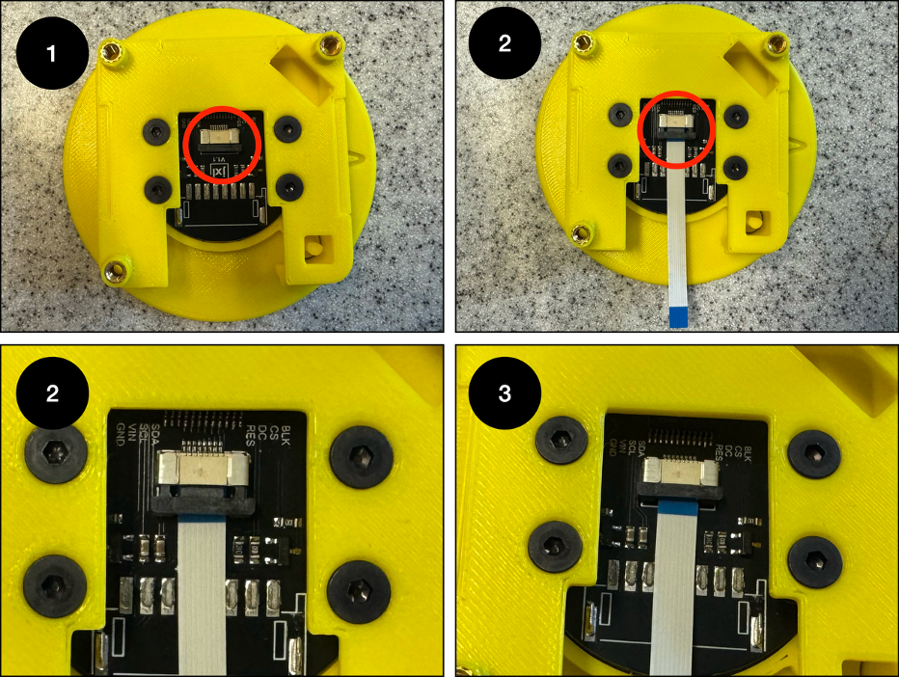
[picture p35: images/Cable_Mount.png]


---

### 7.3 ProcessorPCB and Display Connections

Now connect the displays to the **ProcessorPCB**.

Each connector on the ProcessorPCB is labelled as follows:  
**TOP**, **BOTTOM**, **LEFT**, **RIGHT**, **FRONT**, **BACK**

Start with the **yellow display cup** that does **not** contain the USB-C charger port.  
This cup connects to the **ProcessorPCB**.

**Instructions:**

1. Insert the **short 60 mm FPC cable** into the display connector of the **rear (yellow) display cup** (see previous section).  
2. While holding the ProcessorPCB vertically, insert the same cable into the **rightmost connector** on the board, labelled *BACK*.  
3. Attach the ProcessorPCB to the yellow cup using **M3 hex screws**.  
4. Unlock the remaining five FPC connectors on the ProcessorPCB.  
5. Insert the following FPC cables:
   - Four **medium-length** cables into *TOP*, *BOTTOM*, *LEFT*, and *RIGHT* connectors.  
   - One **long** cable into the *FRONT* connector.  
   - Leave the *FRONT* cable disconnected for now from the display side.  
6. Remember: the **blue side** of each cable must face **away** from the indentation of the connector.

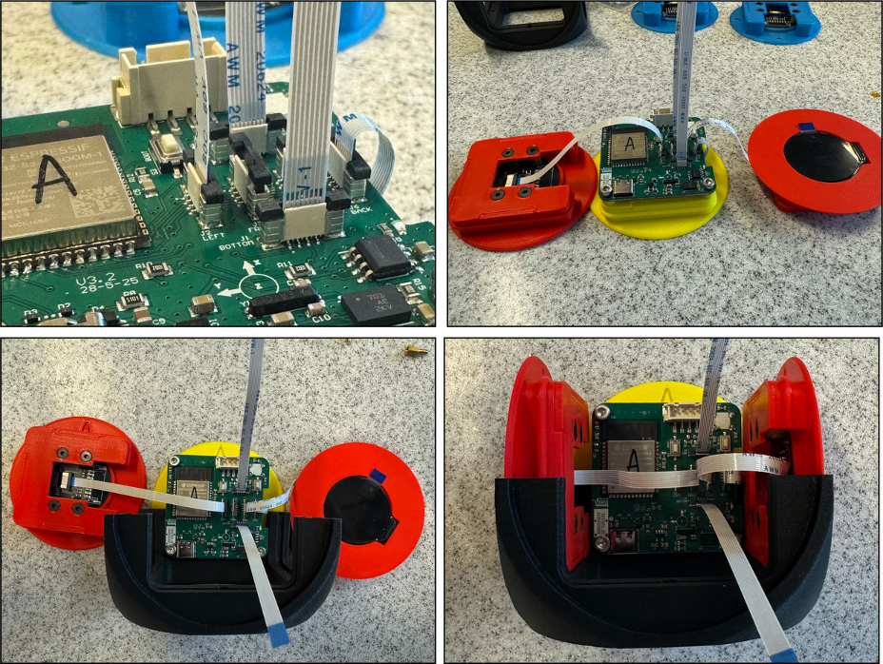
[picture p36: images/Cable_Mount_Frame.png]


---

### 7.4 Left and Right (Red) Display Cup Installation

Repeat the same process for the **Left** and **Right** (red) display cups.

1. Insert each FPC cable into its display connector.  
2. Attach the other ends to the **LEFT** and **RIGHT** connectors on the ProcessorPCB.  
3. Place the **lower black frame** on its side.  
   You can now install the **rear yellow cup** (with ProcessorPCB) into the frame, followed by the two **red cups**.

---

### 7.5 PowerPCB and Front Display Cup

Next, prepare the **front (yellow) display cup**.  
This one holds the **PowerPCB** and the **battery**.

1. Insert the **long FPC cable** into the yellow display connector (the one with the **USB-C port**).  
2. Attach the **PowerPCB** to the cup using **M3 hex screws**, ensuring the USB-C port aligns with its opening.  
3. Mount **M3×6 + 6 mm standoffs** onto the corners of the PowerPCB.  
4. Connect the **charger** and **battery cables** to the PowerPCB.  
5. Use **double-sided foam tape** to fix the **battery** onto its **holder**.  
6. Mount the **battery holder** (with battery attached) onto the **standoffs**.  
7. Connect the **four-wire power cable** between the **PowerPCB** and **ProcessorPCB**.  
8. Finally, connect the **long FPC cable** (from the front display) to the **FRONT connector** on the ProcessorPCB.

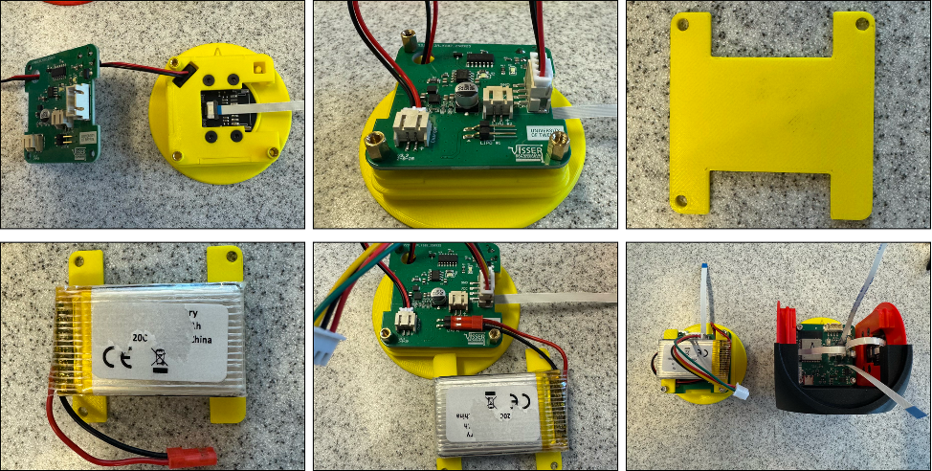
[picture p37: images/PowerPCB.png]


From januari 2026 a different connector of the lipo battery is in use (JST-PH 2.0). See image on how to connect this battery to the PowerPCB.
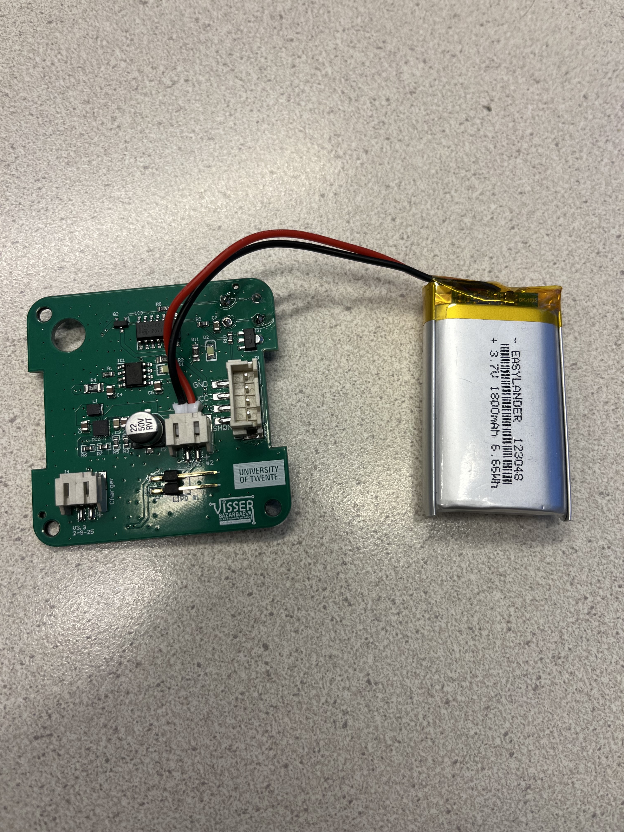
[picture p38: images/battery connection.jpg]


---

### 7.6 Testing the Displays

At this stage, it is recommended to **test all displays**.

1. Connect the **four-wire power cable** to the ProcessorPCB.  
2. Switch on the power by pressing the **front push button** (located on the cup marked with a small circular indentation).  
3. All displays should show the **startup sequence**, including the **current battery voltage**.  

If one or more displays remain blank, check all FPC connections and ensure each latch is properly closed.

> **Tip:**  
> You may want to cover the green indicator LED with a small piece of tape to diffuse the light during operation.

---

### 7.7 Mounting the Display Cups into the Frame

Now you can begin placing the display cups into the **lower black frame** and close it with the **upper frame**.

1. Insert the **four side display cups** (left, right, front, back) into the lower frame.  
   Ensure that the **V-marking** inside each cup points **upwards**.  
2. **Avoid tension** or sharp bends in the FPC cables.  
   Gently guide the cables so they fold neatly inside the central cavity of the dice.

> Excessive stress or bending can damage the FPC cables. Handle them carefully.

1. Test the display connections again by powering on the dice.  
2. Slide the **upper frame** onto the lower frame, ensuring that the cables do not become pinched.  
   Press down evenly until the two halves fit together securely.

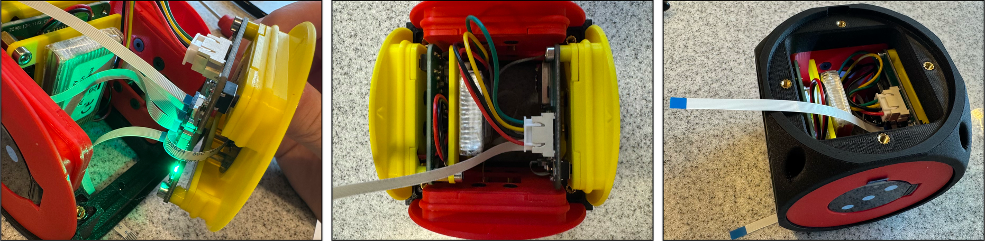
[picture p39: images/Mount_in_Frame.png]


---

### 7.8 Bottom Display Cup (Blue)

1. Guide the **bottom FPC cable** through the opening in the lower frame.  
2. Ensure that the **blue side of the cable** faces upwards.  
3. Insert the FPC cable into the display connector and close the latch.  
4. Mount the **bottom blue display cup** into the frame, but do **not fully fix it** yet.

---

### 7.9 Top Display Cup (Blue)

1. Use the **blue display cup**
2. Check that all connections are secure and aligned.  
3. Screw the **top display cup** firmly into place.

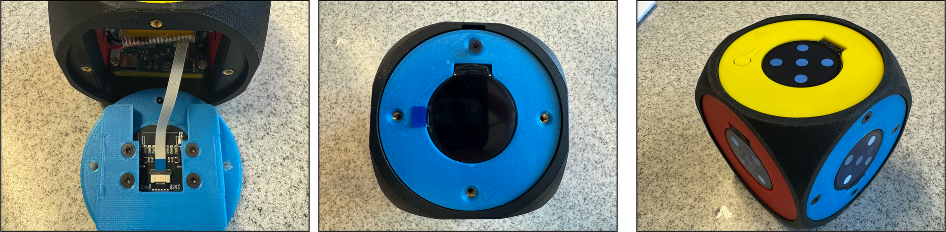
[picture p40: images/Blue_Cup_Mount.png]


---

### 7.10 Final Testing and Completion

Power on the Quantum Die once more to confirm that all six displays light up correctly and the startup sequence appears. The dice should now function automatically if you are using PCBs sourced from the **University of Twente**.

---

## Congratulations

You have successfully built your own **Quantum Die**.  
When used in a pair, the dice will communicate automatically based on their configured MAC addresses (*A – Alice* and *B – Bob*).  
Your Quantum Dice are now ready for demonstration, experimentation, or educational use.

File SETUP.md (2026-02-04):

# 🎲 Quantum Dice Setup Guide

**Welcome!** This guide will walk you through setting up your Quantum Dice step-by-step. Don't worry if you're not technical – we've designed this guide to be easy to follow. Just take it one step at a time, and you'll have your Quantum Dice up and running in no time!

This is a comprehensive guide, starting from a fresh, never used before ESP32 board. If you get your ProcessorBoard from the University of Twente, the configuration is already done and a configuration file is present. For firmware updates or configuration file update you can directly jump to [Updating Your Dice Later](#updating-your-dice-later).

---

## 📑 Table of Contents

1. [What You'll Need](#what-youll-need)
2. [Understanding the Setup Process](#understanding-the-setup-process)
3. [Quick Reference: Common Tasks](#quick-reference-common-tasks)
4. [Getting Started](#getting-started)
   - [Downloading the Firmware Files](#step-1-download-the-firmware-files)
5. [Installing the Main Program](#installing-the-main-program)
   - [Flashing the Quantum Dice Firmware](#step-2-flash-the-quantum-dice-firmware-to-both-dice)
   - [Preparing Your Configuration File (Optional)](#step-3-optional-prepare-your-configuration-file)
   - [Uploading Your Configuration File (Optional)](#step-4-optional-upload-your-configuration-file)
   - [Verifying Everything Works](#step-5-verify-everything-works)
6. [Updating Your Dice Later](#updating-your-dice-later)
   - [Updating the Firmware](#updating-the-firmware)
   - [Updating Your Configuration File](#updating-your-configuration-file)
7. [Troubleshooting](#troubleshooting)
8. [Need More Help?](#need-more-help)

---

## What You'll Need

Before you begin, gather these items:

### Required Items

- ✅ **Your Quantum Dice** with displays removed
- ✅ **Computer** with internet access
- ✅ **USB-C cable** that supports data transfer (not just charging)
- ✅ **Web browser**: Chrome, Edge, or Opera (Safari and Firefox won't work)

### About Your Dice

- The USB-C connector is located on the **bottom side** of each dice
- You'll need to connect each dice **separately** during setup

---

## Understanding the Setup Process

**Don't worry – this might look like a lot, but it's simpler than it seems!**

Here's what we'll do in plain English:

1. **Download files** – Get the software files from the internet
2. **Install the main program** - Load the Quantum Dice software
3. **(Optional) Upload configuration** - Put your settings on the dice
4. **Test** - Make sure everything works!

Both the itial setup and future updates wil take approximitely 5 minutes per dice!

---

## Quick Reference: Common Tasks

**Use this section if you've already set up your dice and just need to do a quick update:**

### Updating the Firmware

1. [Download new firmware files](#step-1-download-the-firmware-files)
2. Connect to ESPConnect
3. [Flash the new firmware](#step-2-flash-the-quantum-dice-firmware-to-both-dice) *(remember to set Flash Offset to `0x10000`)*

### Updating Your Configuration File

1. Connect to ESPConnect
2. [Upload your updated config file](#step-4-optional-upload-your-configuration-file)

---

## Getting Started

### Step 1: Download the Firmware Files

**What you're doing:** Getting the software programs that run your Quantum Dice.

1. **Open your web browser** and go to:  
   [https://github.com/qlab-utwente/Quantum-Dice-by-UTwente/releases/](https://github.com/qlab-utwente/Quantum-Dice-by-UTwente/releases)


2. **Look for the latest release** at the top of the page (it will have a version number like v2.0.0)

3. **Download the files:**
   - `QuantumDice.vX.X.X.bin` – (X.X.X will be version numbers)
   - `QuantumDice.vX.X.X.merged.bin`

✅ **You're done with Step 1!**

---

## Installing the Main Program

### Step 2: Flash the Quantum Dice Firmware to Both Dice

**What you're doing:** Installing the main Quantum Dice program the dice.

**With your dice connected:**

1. **In ESPConnect, click "Flash Tools"** in the left sidebar

2. **Scroll to the "Flash Firmware" section**

3. **Click "Firmware binary (.bin)"** button

4. **Select the file** `QuantumDice.vX.X.X.merged.bin` (from Step 1)

5. **Click "⚡ Flash firmware"**

6. **Wait** for the upload to complete (about 30 seconds to 1 minute)

7. **Success!** You should see "Flash complete"

8. **Repeat for all your dice:**
    - Disconnect the current dice
    - Connect the next dice
    - Follow the same steps (steps 1-7 above)

✅ **Quantum Dice firmware is now installed on all dice!**

---

### Step 3: (Optional) Prepare Your Configuration File

**What you're doing:** Creating a file that tells your dice how to behave.

1. **Download the example configuration file:**  
   [TEST1_config.txt](TEST1_config.txt) *(right-click and "Save Link As...")*

2. **Open the file** your text editor

3. **Read the instructions** inside the file – they explain what each setting does

4. **Adjust the settings** if needed (colors, timeouts, etc.) – the default values work well for most users

5. **Save the file** with your new name:
   - Save it as `YOURNAME_config.txt`

✅ **You're done with Step 3!**

### Step 4: (Optional) Upload Your Configuration File

**What you're doing:** Putting your configuration settings onto your dice.

**Make sure your dice is still connected.**

1. **In ESPConnect, click "LittleFS Tools"** in the left sidebar

2. **Click "Download Backup"** button
   - This is a safety step required before uploading
   - Even if there's nothing to back up, click it anyway
   - Wait for it to complete

3. **After the backup completes**, the "Upload File" section will become available

4. **Click "Choose File"**

5. **Select your configuration file** (e.g., `YOURNAME_config.txt`)

6. **Click "Upload"** – the file uploads to your browser only (not to the dice yet!)

7. **Click "SAVE TO FLASH"** button

8. **Confirm** when asked (click "OK" or "Yes")

9. **Wait** for the upload to complete

10. **Verify the upload:**
    - Look for the eye icon next to your file
    - Click it to view the contents
    - Make sure it matches your configuration file

✅ **Configuration uploaded your dice!**

---

### Step 5: Verify Everything Works

**What you're doing:** Making sure your dice are working correctly.

#### Method 1: Visual Test (If Displays Are Connected)

1. **Watch for the startup sequence:**
   - You should see logos and animations
   - The dice should display properly

✅ **If you see the startup sequence, your dice are working!**

#### Method 2: Serial Monitor Test

**This method works even without displays attached.**

1. **Connect a dice to your computer**

2. **In ESPConnect, click "Serial Monitor"** in the left sidebar

3. **Click "Start"** button

4. **Watch the text output** – you should see something like:

```text
   [LOG]	
   [LOG]	╔════════════════════════════════════════╗
   [LOG]	║      QUANTUM DICE INITIALIZATION       ║
   [LOG]	╚════════════════════════════════════════╝

   [LOG]	/home/twan/Development/Quantum-Dice-by-UTwente/QuantumDice/QuantumDice.ino Jan 26 2026 21:09:54
   [L] FW: 2.0.0
   [LOG]	Step 1: Initializing filesystem and configuration...
   [LOG]	
   [DEBUG]	Mounting LittleFS...
   [DEBUG]	LittleFS mounted successfully
   [D] Total: 4194304 bytes, Used: 8192 bytes
   [D] Found config file: YOURNAME_config.txt
   ...
```

5. **What to look for:**
   - ✅ "Config loaded successfully"
   - ✅ "LittleFS mounted successfully"
   - ✅ "ESP-NOW initialized successfully"
   - ✅ Your dice ID appears correctly
   - ⚠️ You might see some I2C error messages – these are usually okay if sensors initialize afterward

✅ **If you see "Setup complete!" you're all done!**

---

## Updating Your Dice Later

### Updating the Firmware

**When a new version comes out, here's how to update:**

1. **Download the new firmware file** (go to [Step 1](#step-1-download-the-firmware-files))

2. **Connect your dice to your computer**

3. **Open ESPConnect** and connect to your dice

4. **Flash the new firmware** ([Step 2](#step-2-flash-the-quantum-dice-firmware-to-both-dice))
   - Go to the Flash Tools
   - Select the `QuantumDice.vX.X.X.bin` file **!IMPORTANT do not select the merged.bin file**
   - Set Flash Offset to `0x10000` **or** Select `app0` in the recommended offsets
   - Don't erase flash! This will delete all configuration

5. **Repeat for the other dice**

That's it! Your configuration stays intact.

---

### Updating Your Configuration File

**If you need to change settings:**

1. **Edit your configuration file** on your computer

2. **Connect your dice to your computer**

3. **Open ESPConnect** and connect to your dice

4. **Upload the new config file** ([Step 4](#step-4-optional-upload-your-configuration-file))

5. **Repeat for the other dice**

> Note: It is not required for dice to share the same configuration. For example, two dice can have fully distinct entanglement colours, and still cooperate with the correct colours.

---

## Troubleshooting

### "WebSerial API is not supported"

**What this means:** Your browser doesn't support the tool we need.

**Solutions:**

- ✅ Switch to Chrome, Edge, or Opera browser
- ✅ Update your browser to the latest version
- ❌ Safari and Firefox don't work – you must use Chrome, Edge, or Opera

---

### "Cannot connect to serial port" or "Port is not available"

**What this means:** Something is blocking access to your dice.

**Solutions:**

- ✅ Close Arduino IDE, PuTTY, or any other program that might be using the port
- ✅ Disconnect and reconnect your USB cable
- ✅ Try a different USB port on your computer
- ✅ Try a different USB-C cable (some cables are charge-only)
- ✅ Restart your computer if the problem persists

**To check if your computer sees the device:**

- **Windows:** Open Device Manager → look under "Ports (COM & LPT)"
- **Mac:** Open Terminal → type `ls /dev/tty.*` and press Enter
- **Linux:** Open Terminal → type `ls /dev/tty*` and press Enter

---

### "Flash failed" or "Upload failed"

**Solutions:**

- ✅ Check your USB cable – make sure it supports data transfer
- ✅ Try holding the BOOT button on your dice while clicking "Flash firmware"
- ✅ Make sure Flash Offset is set correctly:
  - `0x0` for initial upload with the `vX.X.X.merged.bin` file
  - `0x10000` for software updates with the `vX.X.X.bin` file
- ✅ Try a different USB port
- ✅ Make sure no other program is using the serial port

---

### Configuration File Not Loading

**Signs:** Serial monitor shows "No config file found" and creates and uses `DEFAULT_config.txt`.

**Solutions:**

- ✅ Make sure your filename matches the pattern: `XXXXX_config.txt` (5 letters before _config.txt)
- ✅ Check that Flash Offset was `0x10000` when you flashed the main firmware
- ✅ Try uploading the config file again ([Step 4](#step-4-optional-upload-your-configuration-file))
- ✅ Use the eye icon in LittleFS Tools to verify the file is actually on the dice

---

### Dice Show Errors on Serial Monitor

**I2C Errors:**

```
E (3535) i2c.master: I2C transaction unexpected nack detected
```

These are usually **normal** if you see "BNO055 initialization complete!" afterward. The sensors are just taking a moment to respond.

**Real Problems to Watch For:**

- ❌ "LittleFS mount failed" – means storage wasn't set up properly, try flashing the firmware again with the merged.bin file
- ❌ "Config load failed" – means your config file has errors or wasn't uploaded
- ❌ Setup never completes – check all previous steps

---

## Need More Help?

If you're stuck:

1. **Double-check you followed each step** – it's easy to miss something small!

2. **Look at the serial monitor output** – it often tells you exactly what's wrong

3. **Try the process on the other dice** – sometimes one dice has an issue but the other works fine

4. **Reach out for support:**
   - Check the GitHub repository for updates: [https://github.com/qlab-utwente/Quantum-Dice-by-UTwente](https://github.com/qlab-utwente/Quantum-Dice-by-UTwente)
   - Create an issue on GitHub with:
     - What step you're on
     - What error message you see
     - What you've already tried

---

## 🎉 Congratulations

You've successfully set up your Quantum Dice! The hard part is done. From now on, updates are quick and easy.

**Enjoy your Quantum Dice!** 🎲

---

*Document Version 2.0 – Last Updated: January 2026*

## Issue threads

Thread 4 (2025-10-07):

error compiling esp32 v3.3.0

ator1811, 2025-10-07:
error compiling with esp32 version 3.3.0 (no errors with esp32 v3.2.1)
```
In file included from /Users/user123/Github/Quantum-Dice-by-UTwente/Arduino/QuantumDice/StateMachine.cpp:9:
/Users/user123/Github/Quantum-Dice-by-UTwente/Arduino/QuantumDice/EspNowSensor.h: In instantiation of 'void EspNowSensor<T>::init(uint8_t*) [with T = _message; uint8_t = unsigned char]':
/Users/user123/Github/Quantum-Dice-by-UTwente/Arduino/QuantumDice/EspNowSensor.h:61:15:   required from 'static void EspNowSensor<T>::Init(uint8_t*) [with T = _message; uint8_t = unsigned char]'
   61 |     instance->init(rssiCompareAddr);
      |     ~~~~~~~~~~^~~~
/Users/user123/Github/Quantum-Dice-by-UTwente/Arduino/QuantumDice/StateMachine.cpp:252:30:   required from here
  252 |   EspNowSensor<message>::Init(deviceA_mac);
      |   ~~~~~~~~~~~~~~~~~~~~~~~~~~~^~~~~~~~~~~~~
/Users/user123/Github/Quantum-Dice-by-UTwente/Arduino/QuantumDice/EspNowSensor.h:146:27: error: invalid conversion from 'void (*)(const uint8_t*, esp_now_send_status_t)' {aka 'void (*)(const unsigned char*, esp_now_send_status_t)'} to 'esp_now_send_cb_t' {aka 'void (*)(const wifi_tx_info_t*, esp_now_send_status_t)'} [-fpermissive]
  146 |   esp_now_register_send_cb(EspNowSensor<T>::OnDataSend);
      |   ~~~~~~~~~~~~~~~~~~~~~~~~^~~~~~~~~~~~~~~~~~~~~~~~~~~~~
      |                           |
      |                           void (*)(const uint8_t*, esp_now_send_status_t) {aka void (*)(const unsigned char*, esp_now_send_status_t)}
In file included from /Users/user123/Github/Quantum-Dice-by-UTwente/Arduino/QuantumDice/EspNowSensor.h:9:
/Users/user123/Library/Arduino15/packages/esp32/tools/esp32-arduino-libs/idf-release_v5.5-129cd0d2-v4/esp32s3/include/esp_wifi/include/esp_now.h:185:54: note:   initializing argument 1 of 'esp_err_t esp_now_register_send_cb(esp_now_send_cb_t)'
  185 | esp_err_t esp_now_register_send_cb(esp_now_send_cb_t cb);
      |                                    ~~~~~~~~~~~~~~~~~~^~
exit status 1

Compilation error: invalid conversion from 'void (*)(const uint8_t*, esp_now_send_status_t)' {aka 'void (*)(const unsigned char*, esp_now_send_status_t)'} to 'esp_now_send_cb_t' {aka 'void (*)(const wifi_tx_info_t*, esp_now_send_status_t)'} [-fpermissive]
```

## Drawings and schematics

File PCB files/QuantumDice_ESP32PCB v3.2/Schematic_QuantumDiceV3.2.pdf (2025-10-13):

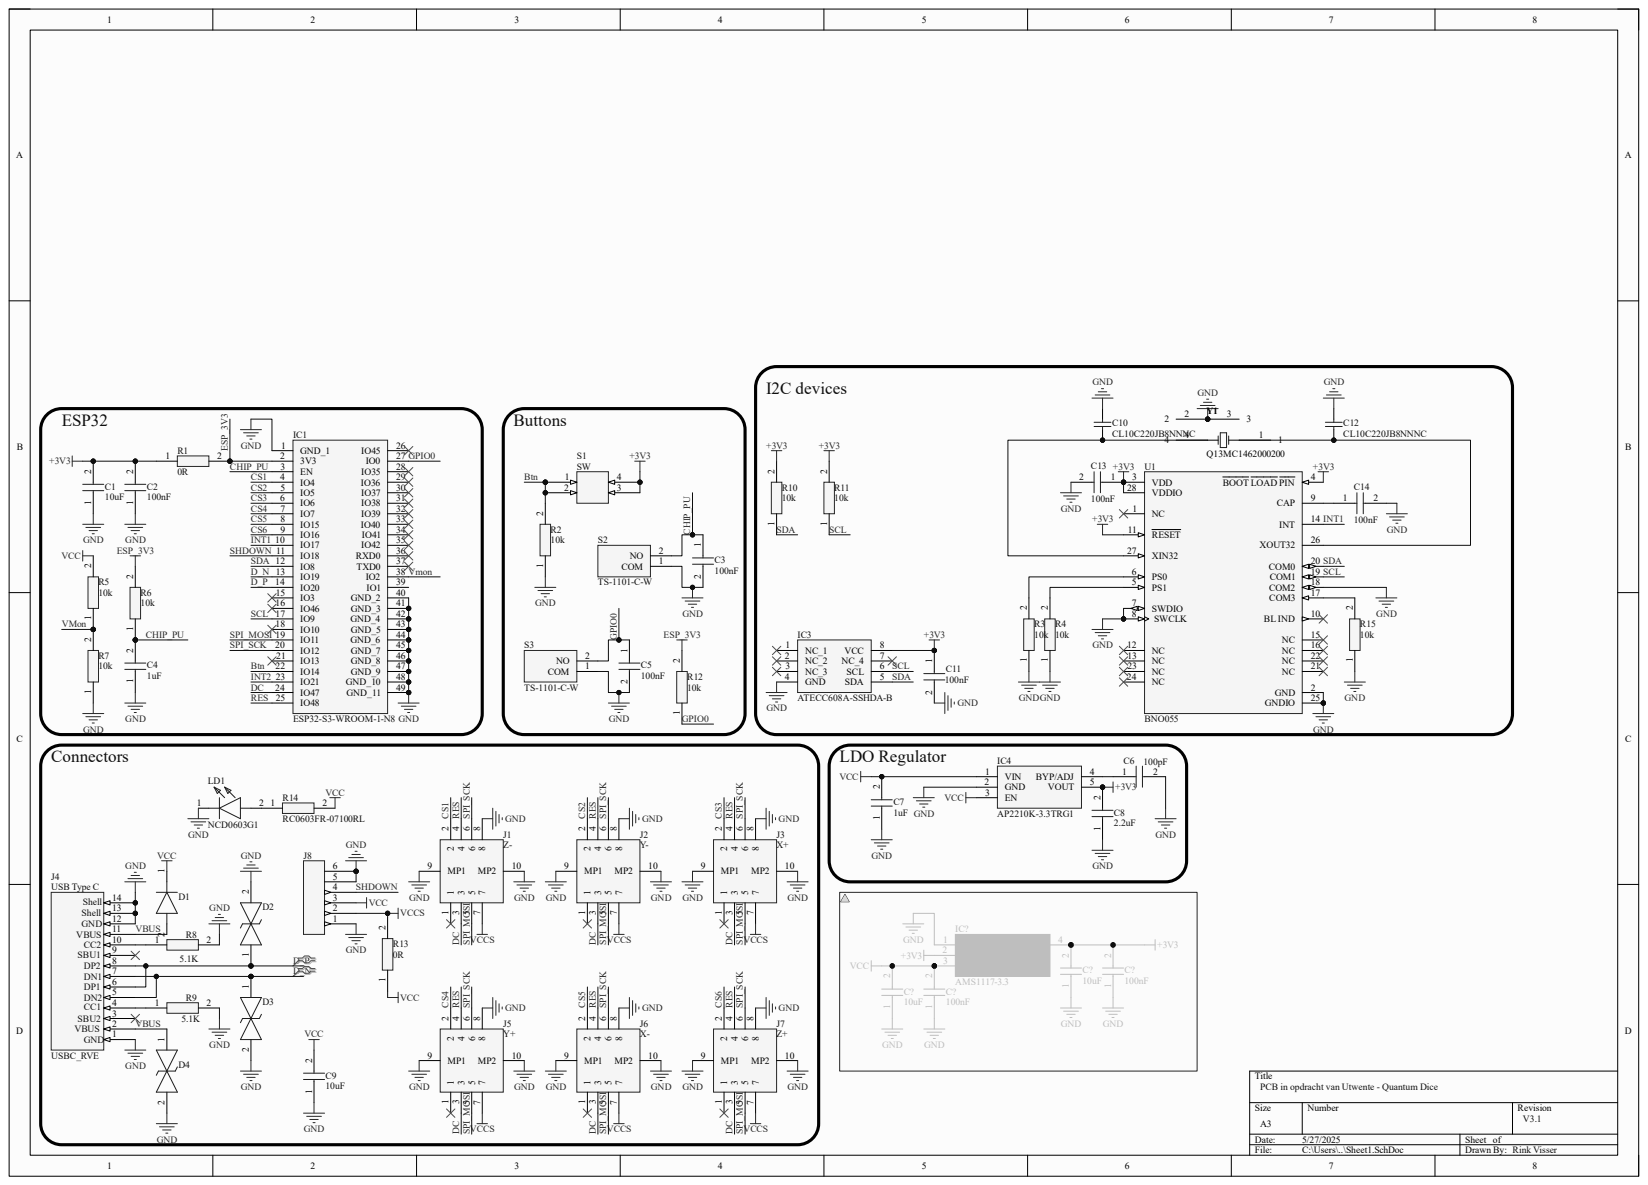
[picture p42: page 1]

Title
PCB in opdracht van Utwente - Quantum Dice

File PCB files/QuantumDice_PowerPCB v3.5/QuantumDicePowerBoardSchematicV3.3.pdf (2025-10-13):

Step up converter | Charging circuit

# 10uF ¹ ²

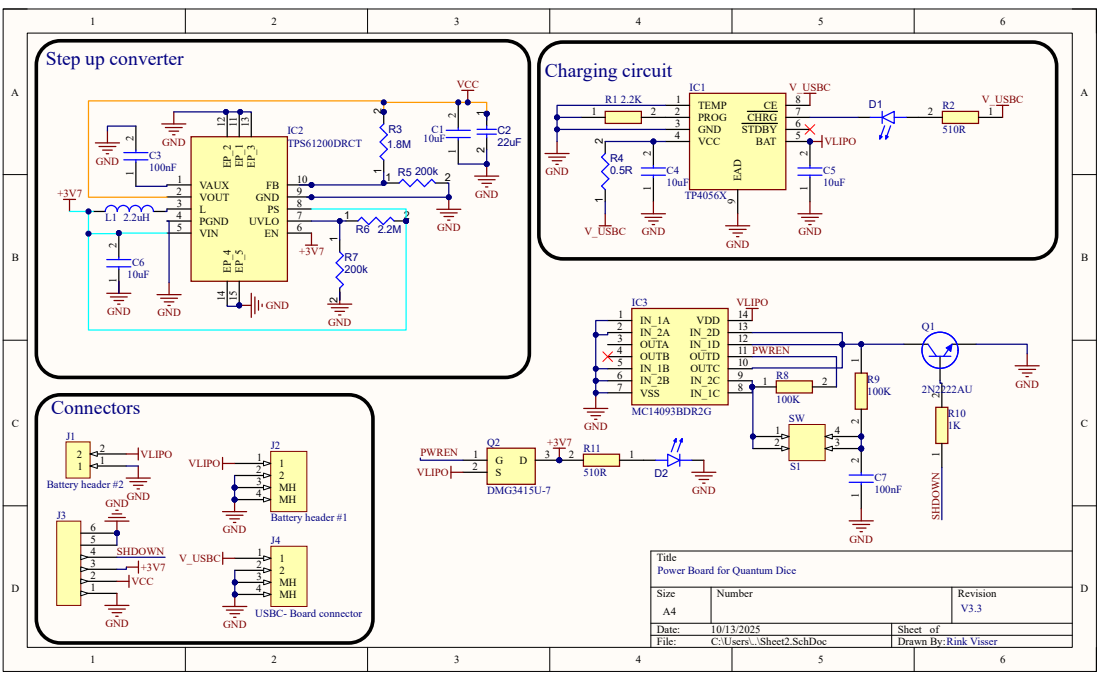
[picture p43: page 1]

Title
Power Board for Quantum Dice

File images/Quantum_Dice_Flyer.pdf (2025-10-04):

## HANDS ON QUANTUM PHYSICS

## QUANTUM DICE

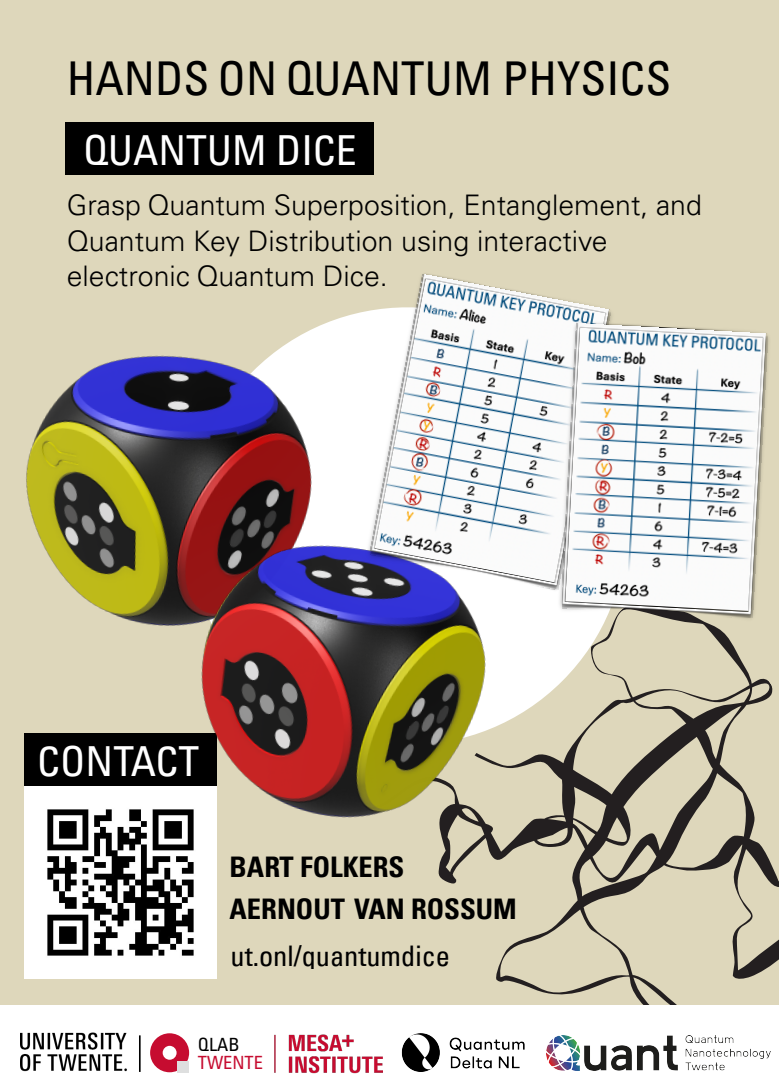
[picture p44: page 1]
CONTACT; QLAB TWENTE

Grasp Quantum Superposition, Entanglement, and
Quantum Key Distribution using interactive
electronic Quantum Dice.

BART FOLKERS
AERNOUT VAN ROSSUM
ut.onl/quantumdice

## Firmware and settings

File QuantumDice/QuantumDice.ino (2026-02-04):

#warning "Compile with Pin Numbering By GPIO (legacy)"
#warning "ESP version 3.3.2 ,board esp32/Arduino Nano ESP32 or esp32/ESP32S3 Dev Module

#include "defines.hpp"
#include "ScreenStateDefs.hpp"
#include "IMUhelpers.hpp"
#include "Screenfunctions.hpp"
#include "handyHelpers.hpp"
#include "StateMachine.hpp"
#include "DiceConfigManager.hpp"

constexpr uint16_t UPDATE_INTERVAL = 50;  //loop functions
constexpr uint8_t SECOND = 1000;

StateMachine stateMachine;

void setup() {
    // Make sure power switch keeps on - do this FIRST before anything else
    pinMode(REGULATOR_PIN, OUTPUT);
    digitalWrite(REGULATOR_PIN, LOW);

    // Initialize serial for debugging
    initSerial();  // delay(1000) included

    // Print version and configuration info
    infoln("╔════════════════════════════════════════╗");
    infoln("║      QUANTUM DICE INITIALIZATION       ║");
    infoln("╚════════════════════════════════════════╝\n");
    infoln(__FILE__ " " __DATE__ " " __TIME__);
    infof("FW: %s\n", VERSION);

    // ═══════════════════════════════════════════════════════════════════
    // Step 1: Initialize LittleFS and ensure config file exists
    // ═══════════════════════════════════════════════════════════════════
    infoln("Step 1: Initializing filesystem and configuration...\n");
    
    if (!ensureLittleFSAndConfig()) {
        errorln("✗ CRITICAL: Failed to initialize filesystem or config!");
        errorln("Device cannot operate. Check serial output above.");
        while(true) { 
            delay(SECOND);  // Halt
        }
    }
    
    infoln("✓ Filesystem and configuration ready!\n");
    
    // Print loaded configuration
    printGlobalConfig();

    // ═══════════════════════════════════════════════════════════════════
    // Step 2: Initialize hardware
    // ═══════════════════════════════════════════════════════════════════
    infoln("Step 2: Initializing hardware...\n");
    
    // intitialise the hardware pins and display addresses
    initHardwarePins();

    infof(" - Dice ID: %s\n", (char*) currentConfig.diceId.c_str());  // Use diceId from config
    infof("Board type: %s\n", currentConfig.isNano ? "NANO" : "DEVKIT");  // Use config instead of defines
    infof("Connection type isSMD: %s\n\n", currentConfig.isSMD ? "SMD" : "HDR");  // Use config instead of defines

    // Initialize displays - now uses hwPins from loaded configuration
    initDisplays();

    // Show startup logo during setup
    displayQLab(ALL);

    // ═══════════════════════════════════════════════════════════════════
    // Step 3: Initialize IMU sensor
    // ═══════════════════════════════════════════════════════════════════
    infoln("Step 3: Initializing IMU sensor...\n");

    // Initialize IMU sensor
    IMUSensor* imuSensor = new BNO055IMUSensor();
    if (!imuSensor->init()) {  // Show initialization progress
        warnln("Failed to initialize sensor!");
    }
    if (currentConfig.isNano) {
        constexpr uint8_t NANO_AXIS_REMAP_CONFIG = 0x06;
        imuSensor->setAxisRemap(NANO_AXIS_REMAP_CONFIG, NANO_AXIS_REMAP_CONFIG);
    }

    imuSensor->update();
    imuSensor->resetTumbleDetection();

    usleep(SECOND);

    welcomeInfo(screenselections::X0);
    voltageIndicator(screenselections::X0);
    displayQRcode(screenselections::X1);

    displayEinstein(screenselections::ZZ);
    displayUTlogo(screenselections::YY);

    usleep(SECOND);
    
    // ═══════════════════════════════════════════════════════════════════
    // Step 4: Complete initialization
    // ═══════════════════════════════════════════════════════════════════
    infoln("Step 4: Completing initialization...\n");

    // Set IMU sensor in state machine
    stateMachine.setImuSensor(imuSensor);

    // Initialize button
    initButton();

    // Initialize the state machine - this sets up ESP-NOW with config MACs
    stateMachine.begin();

    infoln("╔════════════════════════════════════════╗");
    infoln("║       SETUP COMPLETE - READY!          ║");
    infoln("╚════════════════════════════════════════╝\n");
}

void loop() {
    static unsigned long lastUpdateTime = 0;
    unsigned long currentTime = millis();
    if (currentTime - lastUpdateTime >= UPDATE_INTERVAL) {
        button.loop();
        stateMachine.update();
    }
}

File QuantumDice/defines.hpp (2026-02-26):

#ifndef DEFINES_H_
#define DEFINES_H_

#define VERSION "2.0.1"
#define DEFAULT_DICE_ID "DEFAULT"

#define DEBUG 1
#if DEBUG == 1

#define debug(...) Serial.print("[D] "); Serial.print(__VA_ARGS__)
#define debugln(...) Serial.print("[DEBUG]\t"); Serial.print(__VA_ARGS__); Serial.println()
#define debugf(fmt, ...) \
    Serial.print("[D] "); \
    Serial.printf(fmt, __VA_ARGS__)

#else
#define debug(x)
#define debugln(x)
#define debugf(fmt, ...)
#endif

#define info(...) Serial.print("[L] "); Serial.print(__VA_ARGS__)
#define infoln(...) Serial.print("[LOG]\t"); Serial.print(__VA_ARGS__); Serial.println()
#define infof(fmt, ...) \
    Serial.print("[L] "); \
    Serial.printf(fmt, __VA_ARGS__)

#define warn(...) Serial.print("[W] "); Serial.print(__VA_ARGS__)
#define warnln(...) Serial.print("[WARN]\t"); Serial.print(__VA_ARGS__); Serial.println()
#define warnf(fmt, ...) \
    Serial.print("[W] "); \
    Serial.printf(fmt, __VA_ARGS__)

#define error(...) Serial.print("[E] "); Serial.print(__VA_ARGS__)
#define errorln(...) Serial.print("[ERROR]\t"); Serial.print(__VA_ARGS__); Serial.println()
#define errorf(fmt, ...) \
    Serial.print("[E] "); \
    Serial.printf(fmt, __VA_ARGS__)

#define MAXBATERYVOLTAGE 4.00 // under load 4.2 -> 4.0
#define MINBATERYVOLTAGE 3.40
#define BATTERYSTABTIME \
    1000 // waiting time to stabilize battery voltage after diceState change
#define MOVINGTHRESHOLD \
    0.7                      // maximum acceleration magnitude to detect
                             // nonMoving

#define REGULATOR_PIN GPIO_NUM_18 // pin D9
#define BUTTON_PIN GPIO_NUM_14

#endif /* DEFINES_H_ */

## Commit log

2025-10-04 Initial upload
    [01B_Blck_TPU_V7_bottom_frame.stl, 01C_White_PLA_V8_print_support_plate.stl, 02A_Yellow_PLA_V9_display_cup_power.stl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]
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2025-10-10 Update Bill of Material quantum dice.xlsx
    [Bill of Material quantum dice.xlsx]
2025-10-10 Added 3D printmaterial masses; updated links
    [Bill of Material quantum dice.xlsx]
2025-10-10 Update device MACs and adjust entanglement debug output
    Updated MAC addresses for deviceA and deviceB1 in diceConfig.h and increased RSSI sensitivity for entanglement detection. Commented out debug output related to entanglement requests in StateMachine.cpp and handyHelpers.cpp to reduce serial logging noise. Also updated ESP version warning in QuantumDice.ino.
    [QuantumDice.ino, handyHelpers.cpp]
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2025-10-11 Add .gitattributes for diceConfig.h merge strategy
    Specifies 'merge=ours' for Arduino/QuantumDice/diceConfig.h to resolve merge conflicts by favoring local changes.
2025-10-13 Update Arduino README with configuration steps
    Expanded setup instructions to include ProcessorBoard configuration, updated ESP32 board version, clarified library installation, and added details for sensor calibration and cryptographic chip locking. Improves clarity for new users and ensures correct hardware setup.
2025-10-13 Revise and expand Arduino README documentation
    Improved structure with a table of contents, clarified technical descriptions, and expanded setup instructions for the Quantum Dice project. Enhanced configuration steps, corrected typos, and added details for board setup, device calibration, and chip locking procedures to aid user understanding and onboarding.
2025-10-13 Revert "Revise and expand Arduino README documentation"
    This reverts commit dc3996df20e57f20181475f67591a6e581d21be4.
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2025-10-13 Add QuantumDice ESP32 and Power PCB v3 files
    Added BOM, Gerber, pick-and-place, and schematic files for QuantumDice ESP32PCB v3.2 and PowerPCB v3.5. These files support manufacturing and assembly for both board revisions.
    [BOM_QuantumDice PowerPCB v3.5.xlsx, BOM_QuantumDiceV3.2.xls, PickPlace_QuantumDice PowerPCB v3.5.csv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]
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2025-10-16 Refactor to use EEPROM config for hardware and logic
    Replaces compile-time defines and hardcoded values with runtime configuration loaded from EEPROM, including hardware pin assignments, MAC addresses, display colors, and logic constants. Updates all modules to use the new DiceConfig and HardwarePins structures, improving flexibility and maintainability for different board types and dice variants.
    [IMUhelpers.cpp, QuantumDice.ino, Screenfunctions.cpp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]
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2025-10-16 Update and rename quantum dice TPU frame STL files
    Renamed and updated the top and bottom frame STL files for the quantum dice AllTPU parts from V7 to V71, reflecting new revisions to the 3D models.
    [01B_Blck_TPU_V71_bottom_frame.stl, 01B_Blck_TPU_V7_bottom_frame.stl]
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2025-10-17 Add ESP32 web flasher interface
    Introduces a browser-based tool for flashing ESP32 firmware using WebSerial and esptool-js. Supports local file upload and GitHub release selection, serial monitor, erase/reset functions, and progress/status feedback.
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2025-10-17 Update default MAC addresses and UI prompts
    Replaced default MAC addresses for deviceA and deviceB1 with placeholder values. Improved serial prompts for dice ID input and removed redundant instructions from MAC address output.
    [QuantumDiceInitTool.ino]
2025-10-17 Remove QuantumDiceWriteEEEPROM.ino utility script
    Deleted the QuantumDiceWriteEEEPROM.ino file, which was used for initializing and managing EEPROM configuration for Quantum Dice devices. This script is no longer needed or has been superseded by other configuration methods.
2025-10-17 Revamp README with web flasher instructions
    Replaces the original Arduino/README.md with a new, user-friendly guide focused on the web-based firmware flasher for QuantumDice ESP32 devices. The new README provides step-by-step flashing instructions, troubleshooting, and workflow guidance, while the original Arduino programming and configuration instructions are preserved in Arduino/README_old.md for reference.
2025-10-20 Create DiceStateGenerators v2.xlsx
    [DiceStateGenerators v2.xlsx]
2025-10-21 Update TPU frame and bumper plate 3D models
    Renamed and updated top and bottom TPU frame STL files to V81 versions and modified the frame bumper plate 3MF file. These changes likely reflect design improvements or version updates for the quantu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
    [01B_Blck_TPU_V81_bottom_frame.stl, Frame bumper plate.3mf]
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2025-10-21 Update DiceStateGenerators v2.xlsx
    [DiceStateGenerators v2.xlsx]
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2025-10-24 Update DiceStateGenerators v2.xlsx
    included new states and added schematics in mermaid format
    [DiceStateGenerators v2.xlsx]
2025-11-05 Create QD IMU calibrator.stl
    [QD IMU calibrator.stl]
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2025-11-14 Update Bill of Material for quantum dice
    Revised the Bill of Material spreadsheet for the quantum dice project. Changes may include updated components, quantities, or specifications.
    [Bill of Material quantum dice.xlsx]
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2026-01-26 Add note for skipping display connector removal
    Added note to skip display connector removal if sourced from the University of Twente.
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2026-01-27 Update construction manual and BOM for battery changes
    Updated the ConstructionManual.md and PDF to reflect new LiPo battery specifications and connector type (JST-PH 2.0) effective from January 2026. Added new images for battery and connection instructi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
    [Bill of Material quantum dice.xlsx]
2026-01-29 Update Bill of Material quantum dice.xlsx
    add usb charger cable and lipo battery
    [Bill of Material quantum dice.xlsx]
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2026-02-02 Remove AllTPU version and update construction manual
    Deleted all 3D print files related to the AllTPU version of the quantum dice and updated the ConstructionManual.md to reflect that only the TPUFrameOnly version is now applicable. Also removed refere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
    [01A_Blck_TPU_V71_top_frame.stl, 01B_Blck_TPU_V71_bottom_frame.stl, 02A_Yellow_TPU_V7_display_cup_power_USB-C.stl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]
2026-02-04 adapt BoM
    [Bill of Material quantum dice.xlsx]
2026-02-04 Clarify pairing wording and RNG mention
    Edit ConstructionManual.md to simplify and tighten wording: removed a future-supply note about ready-to-use electronic boards, shortened the pairing description (removed explicit A/B labeling) and made minor wording tweaks to the MCU description by changing “true random generator” to “random generator”. These are editorial clarifications to avoid unnecessary detail and to neutralize a stronger claim about the RNG.
2026-02-11 Introduce DEFAULT_DICE_ID and use for defaults
    Add DEFAULT_DICE_ID to defines.hpp and replace hard-coded "DEFAULT" occurrences in DiceConfigManager. The default config ID assignment, the default config filename ("/DEFAULT_config.txt" → "/" DEFAULT_DICE_ID "_config.txt"), and the file's diceId line now use the macro to centralize the default dice identifier and avoid magic strings.
    [defines.hpp]
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2026-03-10 Reorganize 3D print files and update BOM
    Clean up and reorganize 3D print assets: moved TPUFrameOnly parts into a new "Version 2" directory (13 files renamed/moved) to consolidate versioned prints, deleted seven obsolete STL files from Quan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
    [01A_Blck_TPU_V81_top_frame.stl, 01B_Blck_TPU_V81_bottom_frame.stl, 01C_White_PLA_V8_print_support_plate.stl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]
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2026-06-17 Fixed wakeup on usb connect and disconnect
    [QuantumDice.ino, handyHelpers.cpp]
2026-06-17 Inverted z-axis.
2026-06-18 Fix gravity sign; use tft.begin; enum bitmask
    Correct gravity vector assembly in IMU update (remove unintended negation of X component). Use the default tft.begin() call (comment out custom clock parameter) to initialize displays. Refactor screenselections to explicit bitmask values and compose combined selections with bitwise ORs (including ALL and NO_ONE) to enable easier multi-screen selection logic.
    [IMUhelpers.cpp, Screenfunctions.cpp, Screenfunctions.hpp]
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2026-08-31 Restructured the firmware folders.
    [DEV1_config.txt, TEST1_config.txt, partitions.csv]
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2026-09-02 Swap X and Z axis, invert Z axis.
    [IMUhelpers.cpp]
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2026-09-07 Add v4.1 PCB files and v3 3D prints
    Add PCB package for QuantumDice_ESP32PCB v4.1 (BOM, CPL, Gerbers zip, PDF) and several Version 3 3D STL files (frame and display cups). Update 3D print and PCB README files with printing/assembly and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
    [02A_Yellow_PLA_V31_display_cup_battery.stl, 02B_Yellow_PLA_V31_display_cup_ESP32.stl, 02C_Yellow_PLA_V31_display_cup_ESP32_cover.stl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]
2026-09-07 Add Quantum Dice v4.2 PCB design package
    This adds the v4.2 ESP32 PCB package for Quantum Dice, including the BOM, pick-and-place CSV, Gerber archive, and schematic PDF. These files capture the finalized board fabrication and assembly data 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
    [BOM-Quantum_Dice_V2.csv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]
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2026-09-20 Corrected IMU axis.
2026-09-22 Update V3 ESP32 display cup STL files
    Updated the Version 3 yellow PLA display cup and cover STL files for the ESP32 enclosure. These binary CAD revisions adjust the physical model geometry for the display assembly.
    [02B_Yellow_PLA_V31_display_cup_ESP32.stl, 02C_Yellow_PLA_V31_display_cup_ESP32_cover.stl]
2026-09-23 Create Bill of Material quantum dice.ods
    [Bill of Material quantum dice.ods]
2026-09-23 V4.1 removed. Unuseable
    [BOM-Quantum_Dice_V2.csv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]
2026-09-23 Add PCB images and update PCB README
    Add four PCB image assets and update PCB files/README.md to use the new images. Fixed image paths, replaced the assembly screenshot with Ordering_JLCPCB.png, clarified orientation using PCBv4.2_Top_Bottom_view.png, and added a short "Next steps" note about connecting battery/USB/displays and uploading firmware.
2026-09-23 Fix PCB image path and asset naming
    This commit updates the PCB documentation to reference the renamed board image file and aligns the asset name with the v4.2 naming convention. The README path was corrected from the old Windows-style relative path to the new image location.
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2026-09-29 Updated the example config and removed the diceId character limit.
    [EXAMPLE_config.txt, TEST1_config.txt]
2026-09-30 3D prints: promote v4, archive v2, update README
    Add Quantum Dice configuration notes to 3D print README.md (documenting Version 4 as current, Type A/B variants, BOM pointer and archive note). Rename/move Version 3 print artifacts into Version 4 fi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
    [01A_Blck_TPU_V81_top_frame.stl, 01B_Blck_TPU_V81_bottom_frame.stl, 01C_White_PLA_V8_print_support_plate.stl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]
2026-10-01 Organize v4 files and docs
    This change reorganizes the Version 4 print files into a dedicated Type A folder and archives older PCB design files for reference. It also updates the 3D print README to describe the Type A/Type B variants, adds display images, clarifies the variant differences, and fixes wording around support removal and BOM references. The BOM spreadsheet was refreshed and the Type B files are noted as still under construction.
    [02A_Yellow_PLA_V40-A_display_cup_battery.stl, 02B_Yellow_PLA_V40-A_display_cup_ESP32.stl, 02C_Yellow_PLA_V40-A_display_cup_ESP32_cover.stl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]
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2026-10-08 Update assembly docs and images
    Refresh the Quantum Dice construction guide with cleaner markdown formatting, add the cable image to the assembly section, rename the battery image to match the project conventions, and fix the README link to the construction manual.
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
